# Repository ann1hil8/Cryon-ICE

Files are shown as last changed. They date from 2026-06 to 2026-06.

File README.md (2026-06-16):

# Cryon-ICE: High-Performance RISC-V Target Emulator & Hardware Debugger

Cryon-ICE is a high-speed real-time hardware debugger and target emulation platform built on the Microchip PolarFire SoC FPGA architecture. The system serves as an advanced bidirectional interface bridge designed to intercept, analyze, and process target system execution signals with sub-nanosecond timing precision. 

The architecture bridges a multi-core 64-bit Linux-capable RISC-V subsystem and flexible programmable fabric directly to an external emulation pod interface via high-density card edge connectors.

---

## Technical Architecture Overview

### 1. System Function & Target Application
* **Real-Time Emulation:** Provides deterministic, ultra-low-latency tracking and signal injection for vintage and modern processing buses.
* **Signal Intercept:** Actively hooks into address, data, and control structures of external hardware targets through dedicated, direction-controlled level shifters.
* **Bus Topologies:** Supports a universal expansion bus configuration, currently mapped to a physical PCIe card edge connector profile to interface directly with modular target emulation pods.

### 2. Primary Processing Core
The platform core utilizes the **Microchip PolarFire SoC FPGA** which integrates a hardened coherent CPU cluster alongside non-volatile programmable logic fabric.

* **Exact Part Number:** `MPFS025TC-FCVG484I` (Industrial Temperature Variant, 25K Logic Elements).
* **Microprocessor Sub-System (MSS):** * 1x RV64IMAC Monitor Core (E51 Performance Profile).
  * 4x RV64GC Application Cores (U54 Performance Profile, coherent execution cluster).
  * Hardened memory controllers supporting secure boot, asset protection, and full operating system execution (Linux).
* **Reference Baselines:** Hardware schematics and subsystem initialization fabrics are cross-referenced from the **BeagleV-Fire** open-hardware specification and the **MPFS-ICICLE-KIT** (PolarFire SoC Icicle Development Kit) base architectures.

### 3. Physical Mechanical Package
* **Package Designation:** `FCVG484` (Fine Pitch Flip-Chip Ball Grid Array).
* **Physical Package Envelope:** 19.0 mm x 19.0 mm square molded body package size.
* **Pin Matrix Array:** 484 physical active solder spheres mapped to a 22 x 22 structural matrix grid.
* **Ball Pitch ($P$):** 0.8 mm center-to-center pad spacing. This allows routing single escape tracks using conventional, cost-effective mechanical micro-drills rather than high-density interconnect (HDI) laser-vias.

### 4. PCB Design & Layout Constraints

#### Thermal and Decoupling Void
The physical layout strips away all copper landing pads within the center core of the 22 x 22 BGA matrix configuration, mirroring the physical depopulated ring profile of the `FCVG484` package silicon. This provides two critical routing advantages:
* **Decoupling Optimization:** Low-inductance 0.1 uF ceramic decoupling capacitors are placed directly on the bottom side of the PCB (Layer 4/6), directly beneath the processor power balls to suppress high-frequency transients.
* **Thermal Sink:** The internal center cavity is flooded with a continuous, unbroken Ground copper polygon pour on the outer layer, functioning as an integrated cooling block connected directly to internal system return layers.

#### Physical Layer Stackup Blueprint
The system requires a minimum of a 4-Layer or 6-Layer impedance-controlled configuration:
* **Layer 1 (Top/F.Cu):** Microstrip routing paths, BGA outer escape rings, high-speed transceiver runs, and level-shifter landing pads.
* **Layer 2 (Inner 1/In1.Cu):** Continuous, uninterrupted Ground ($GND$) reference plane. Provides immediate shield parameters for high-density breakout tracks.
* **Layer 3 (Inner 2/In2.Cu):** Split Power Plane ($V_{\text{DD}}$ Core Logic, $V_{\text{DDA}}$ Transceiver Supplies, and 3.3 V / 5.0 V I/O Peripheral Rails).
* **Layer 4 (Bottom/B.Cu):** Passives, decoupling capacitors under the BGA core cavity, and secondary escape routing structures.

---

## CAD Design Rules Matrix (KiCad Netclasses)

The board layout is constrained by specific routing rules configured within the project netclass matrix. Tracks are auto-routed and routed manually using single-ended configurations without generating layout violations.

| Net Class Name | Clearance | Track Width | Via Size | Via Drill | uVia Size | uVia Drill | DP Width | DP Gap |
| :--- | :--- | :--- | :--- | :--- | :--- | :--- | :--- | :--- |
| `BGA_Escape` | 0.127 mm | 0.127 mm | 0.400 mm | 0.200 mm | 0.400 mm | 0.200 mm | 0.127 mm | 0.150 mm |
| `Universal_Bus` | 0.150 mm | 0.200 mm | 0.600 mm | 0.300 mm | 0.600 mm | 0.300 mm | 0.200 mm | 0.200 mm |
| `Power_GND` | 0.200 mm | 0.500 mm | 0.800 mm | 0.400 mm | 0.800 mm | 0.400 mm | 0.600 mm | 0.250 mm |
| `Default` | 0.200 mm | 0.200 mm | 0.600 mm | 0.300 mm | 0.300 mm | 0.100 mm | 0.200 mm | 0.250 mm |

### Routing Mechanics
* **BGA Escape Plan:** Escape tracks (0.127 mm width) break out through the diagonal open channels between the BGA pads (0.400 mm pad diameter). Vias are placed inside the center void of each 4-pad diamond cluster to preserve spatial clearances.
* **Bus Expansion:** Upon exiting the physical boundary of the BGA footprint package, traces transition via the `Universal_Bus` netclass rules to 0.200 mm widths to improve trace reliability, signal propagation characteristics, and manufacturing yields over long runs.

---

## Future Roadmap Configurations

### I/O Channel Expansion
* **Target Scale:** Planned upgrade to scale the universal emulation bus up from 48 lines to **64 universal bidirectional I/O channels**.
* **Impact:** Requires mapping additional General Purpose I/O (GPIO) banks from the PolarFire fabric and scaling up the number of transceiver/buffer ICs.

### Alternate Pod Interconnect Profiles
* **Connector Variant Modularity:** Evaluation of replacing or augmenting the baseline standard PCIe card-edge footprint with multi-lane high-density, high-speed connector options (e.g., Amphenol PCIe M.2 Gen 3/Gen 4 card edge or specialized mezzanine interconnects) to decrease overall pod size profiles while protecting high-speed signal integrity.

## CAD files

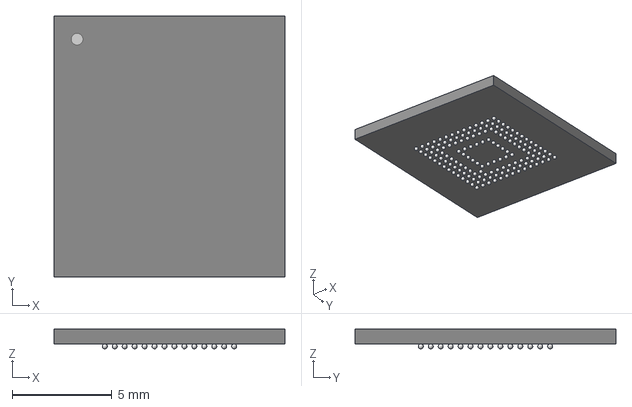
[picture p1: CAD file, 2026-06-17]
Cryon_Library/3D_Models/153BGA_11p5x13x1_MAC.iges
11.6 x 13.1 x 0.993 mm

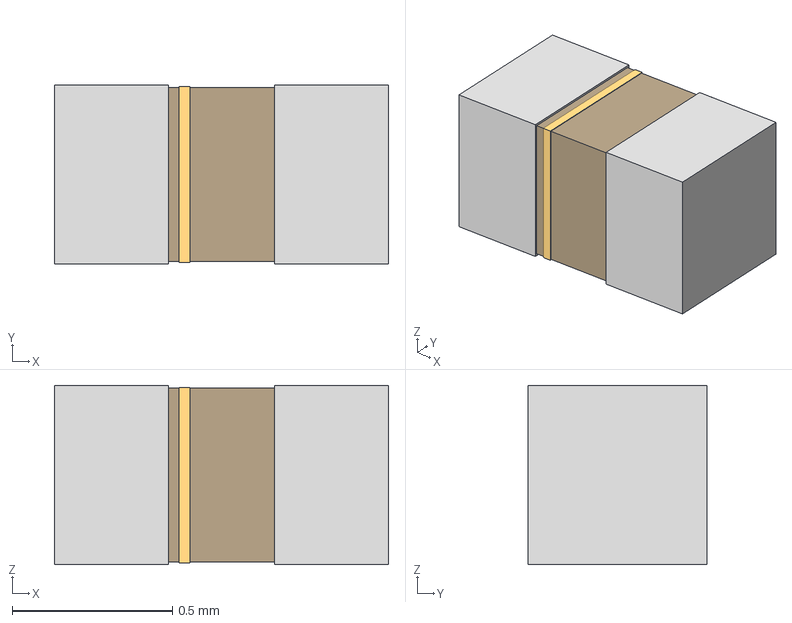
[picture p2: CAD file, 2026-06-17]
Cryon_Library/3D_Models/BLM15P_FBD.iges
1.04 x 0.558 x 0.559 mm

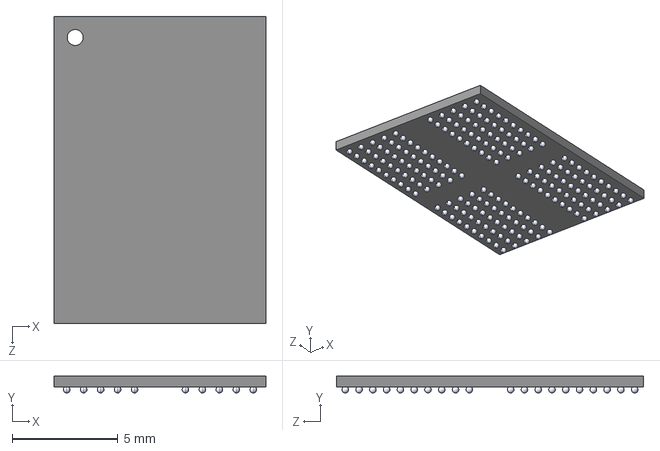
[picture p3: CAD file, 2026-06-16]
Cryon_Library/3D_Models/D1621XM4CDGVI-U.step
10.0 x 0.8 x 14.5 mm

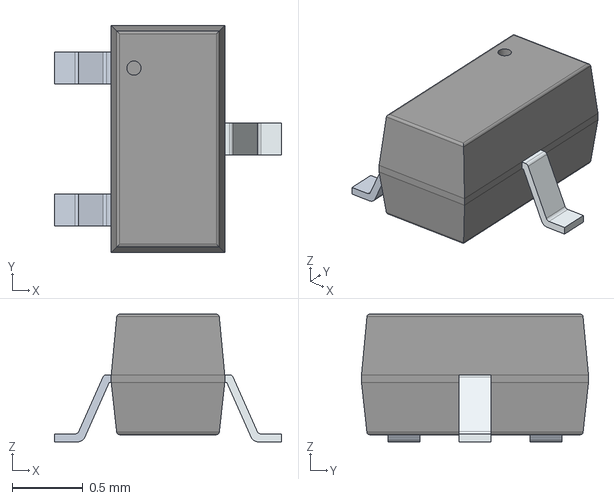
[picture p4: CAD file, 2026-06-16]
Cryon_Library/3D_Models/DMG1012T.iges
1.60 x 1.60 x 0.9 mm

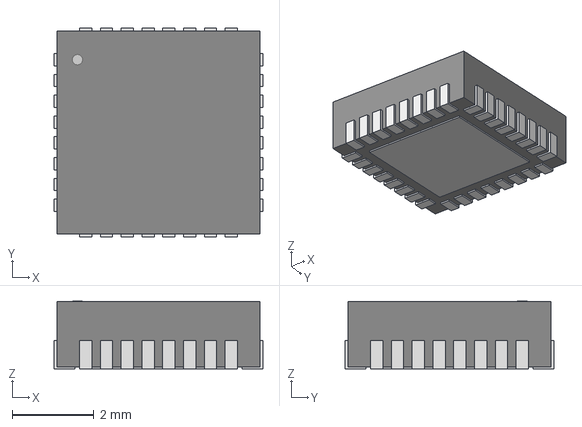
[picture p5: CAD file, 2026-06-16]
Cryon_Library/3D_Models/QFN32_5X5MC_MCH.iges
5.11 x 5.11 x 1.65 mm

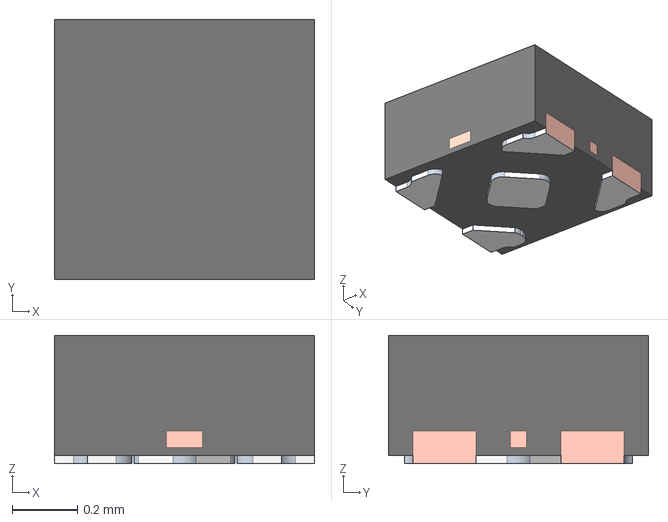
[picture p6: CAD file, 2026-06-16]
Cryon_Library/3D_Models/DPW0005A.iges
0.8 x 0.8 x 0.395 mm

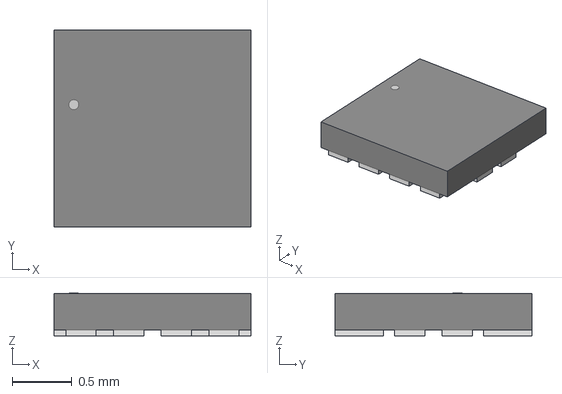
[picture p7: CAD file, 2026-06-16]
Cryon_Library/3D_Models/SOT1355-1_X2QFN12_NXP.iges
1.65 x 1.65 x 0.358 mm

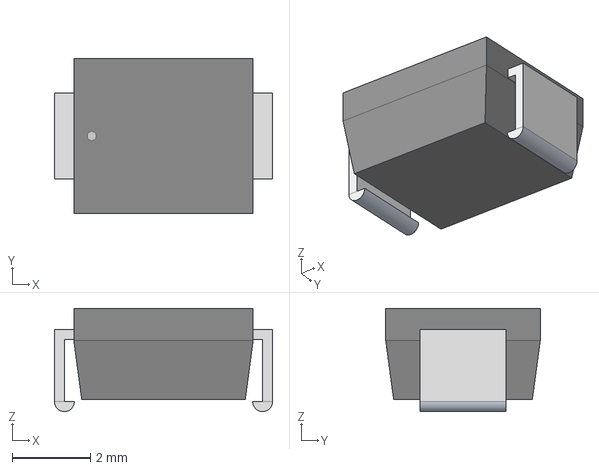
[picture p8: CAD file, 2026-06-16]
Cryon_Library/3D_Models/SMB_STM.iges
5.59 x 3.96 x 2.64 mm

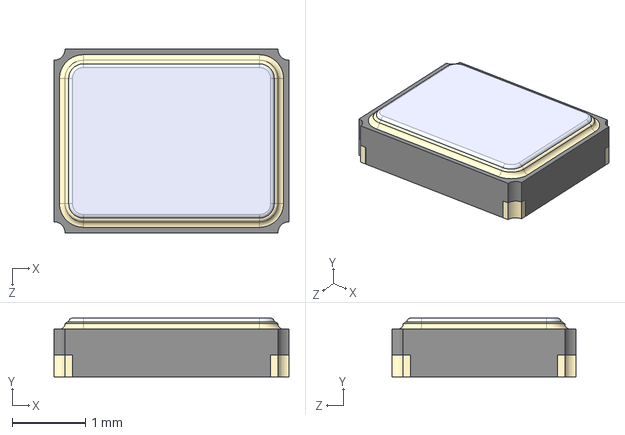
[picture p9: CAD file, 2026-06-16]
Cryon_Library/3D_Models/12-88481.step
3.20 x 0.8 x 2.50 mm

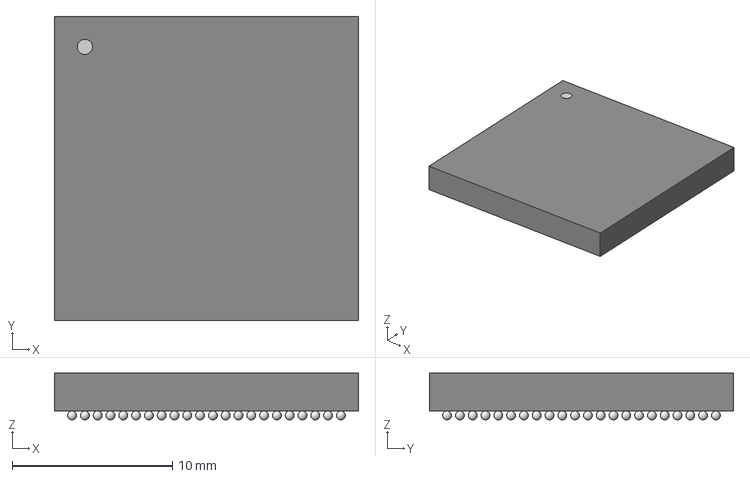
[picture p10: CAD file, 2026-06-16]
Cryon_Library/3D_Models/MPFS250TMPFS160TMPFS095TMPFS025T-FCVG484_MCH.step
19.0 x 19.0 x 2.92 mm

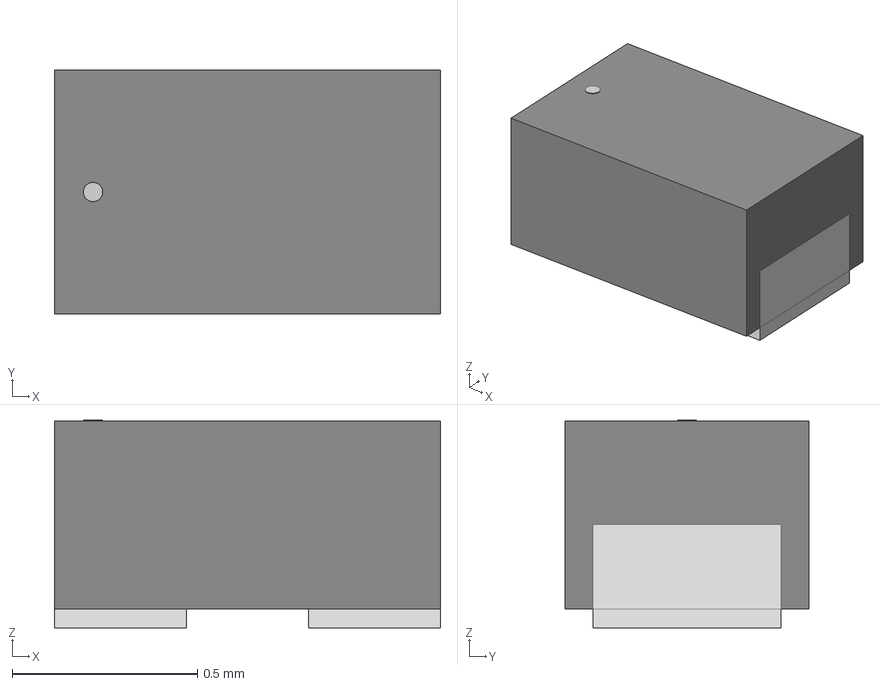
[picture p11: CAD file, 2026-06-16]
Cryon_Library/3D_Models/CR_DFN1006-2_GAS.iges
1.04 x 0.66 x 0.561 mm

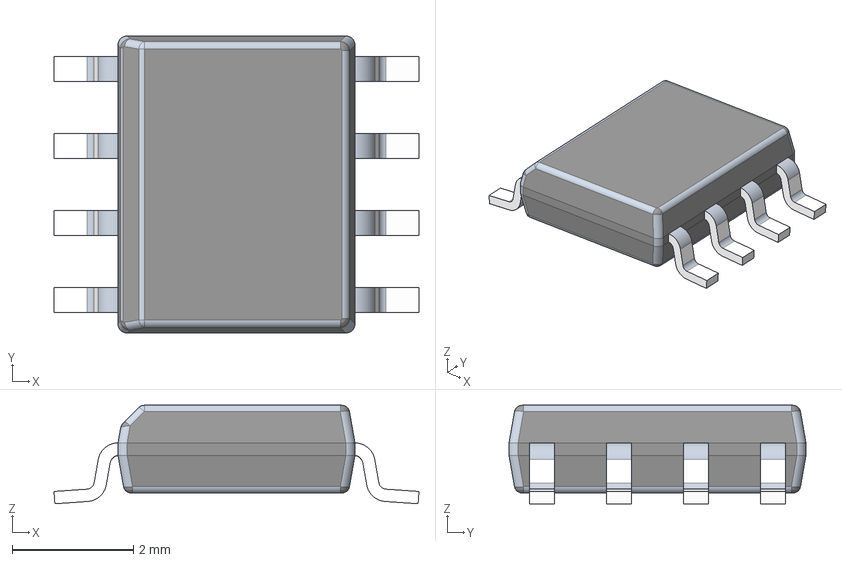
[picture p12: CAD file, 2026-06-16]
Cryon_Library/3D_Models/D0008A.iges
6.02 x 4.90 x 1.63 mm

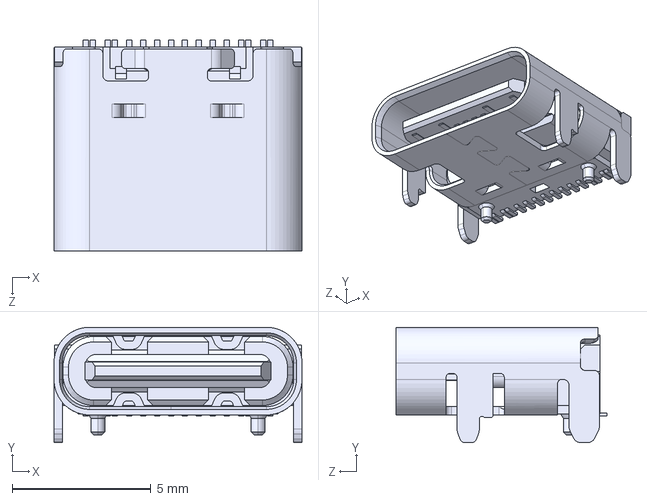
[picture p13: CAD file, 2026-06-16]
Cryon_Library/3D_Models/10155435-00011LF.STEP
8.94 x 4.16 x 7.60 mm

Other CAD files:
Cryon_Library/3D_Models/10155435-00011LF.stp
Cryon_Library/3D_Models/MPFS250TMPFS160TMPFS095TMPFS025T-FCVG484_MCH.iges

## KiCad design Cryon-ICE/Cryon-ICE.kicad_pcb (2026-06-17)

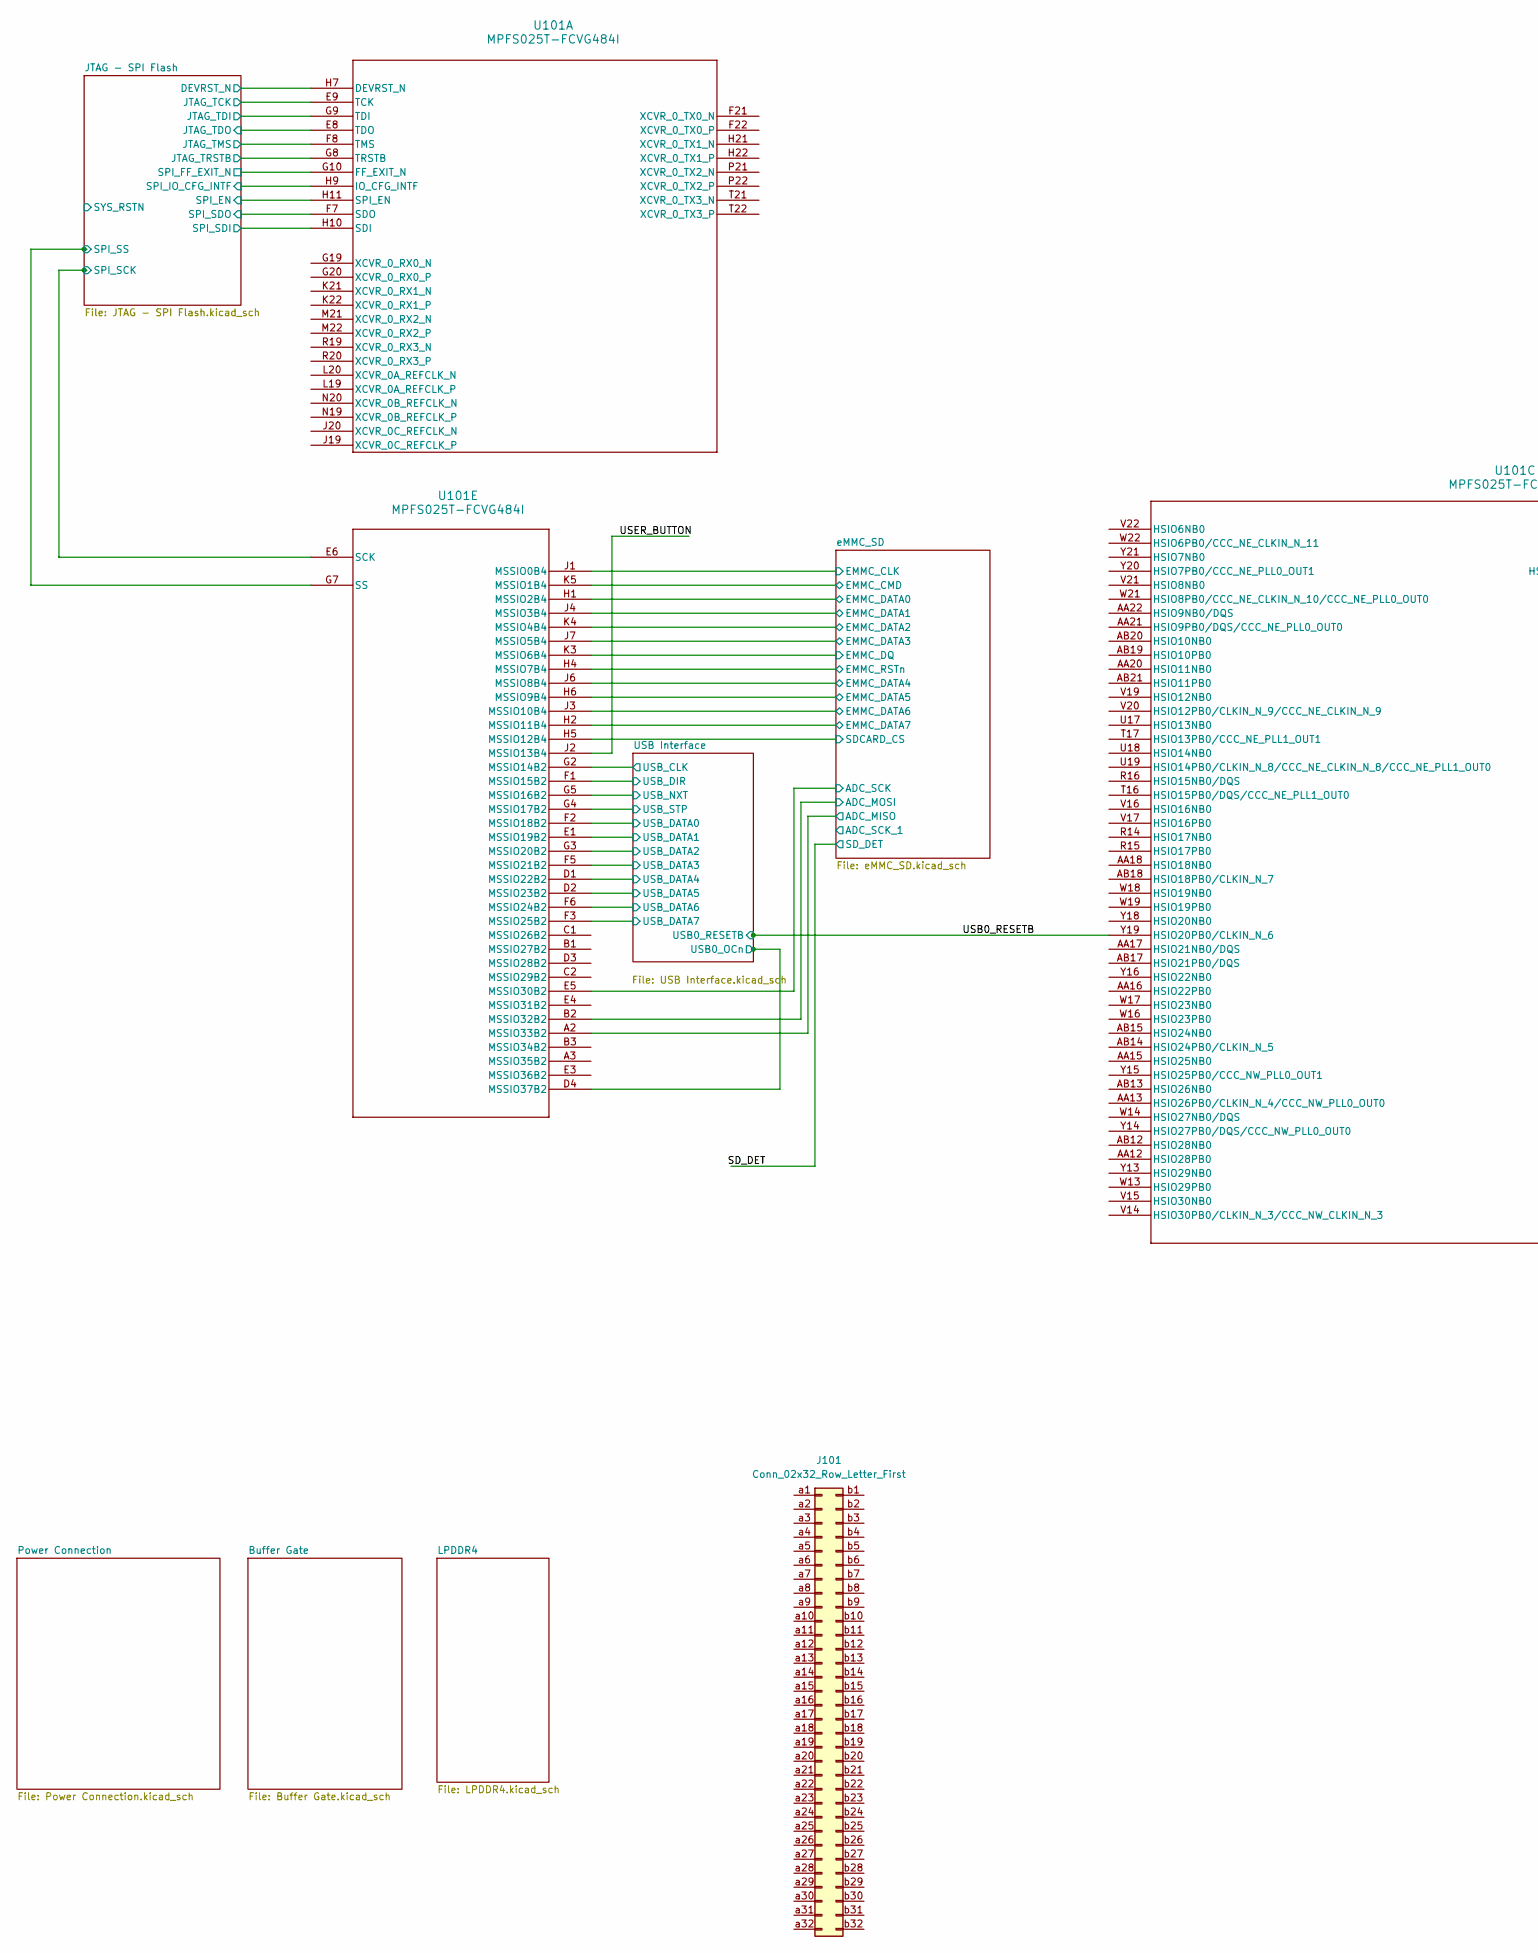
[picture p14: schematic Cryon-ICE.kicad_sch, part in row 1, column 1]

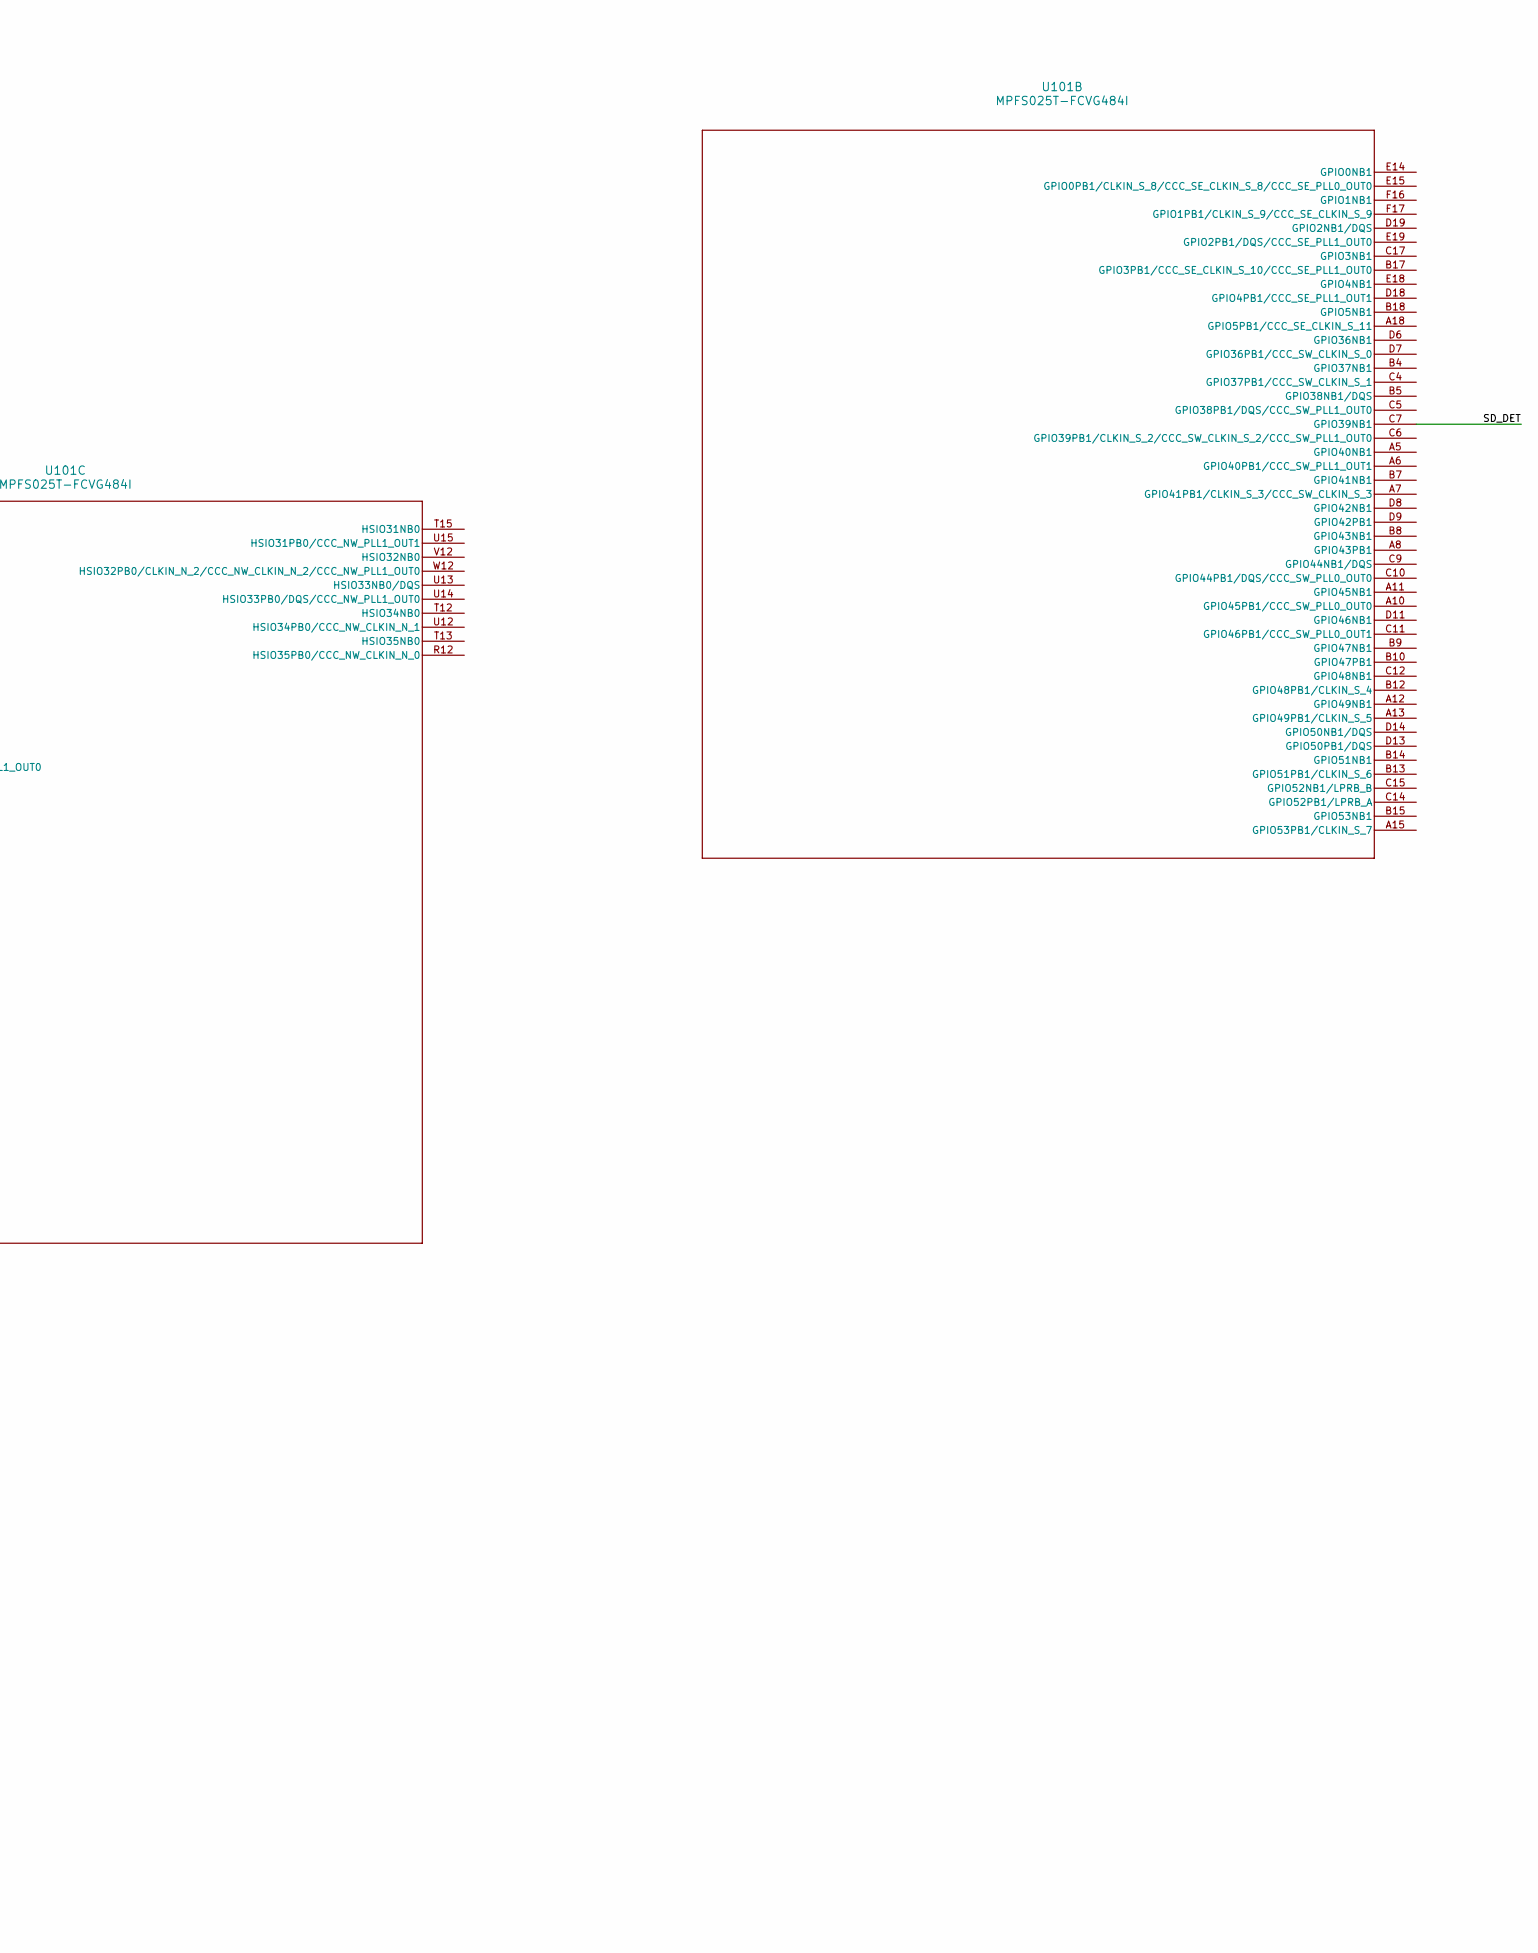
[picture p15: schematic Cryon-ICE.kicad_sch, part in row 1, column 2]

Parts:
J101: Conn_02x32_Row_Letter_First; BUS_PCIexpress_x4
U101: MPFS025T-FCVG484I; MPFS250T&slash_MPFS160T&slash_MPFS095T&slash_MPFS025T-FCVG4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

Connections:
/JTAG - SPI Flash/DEVRST_N: U101.H7 (DEVRST_N); also elsewhere on the board
/JTAG - SPI Flash/JTAG_TDO: U101.E8 (TDO); also elsewhere on the board
/JTAG - SPI Flash/JTAT_TCK: U101.E9 (TCK); also elsewhere on the board
/JTAG - SPI Flash/JTAT_TDI: U101.G9 (TDI); also elsewhere on the board
/JTAG - SPI Flash/JTAT_TMS: U101.F8 (TMS); also elsewhere on the board
/JTAG - SPI Flash/JTAT_TRSTB: U101.G8 (TRSTB); also elsewhere on the board
/JTAG - SPI Flash/SPI_EN: U101.H11 (SPI_EN); also elsewhere on the board
/JTAG - SPI Flash/SPI_FF_EXIT_N: U101.G10 (FF_EXIT_N); also elsewhere on the board
/JTAG - SPI Flash/SPI_MISO: U101.H10 (SDI); also elsewhere on the board
/JTAG - SPI Flash/SPI_MODE: U101.H9 (IO_CFG_INTF); also elsewhere on the board
/JTAG - SPI Flash/SPI_SCK: U101.E6 (SCK); also elsewhere on the board
/JTAG - SPI Flash/SPI_SDO: U101.F7 (SDO); also elsewhere on the board
/JTAG - SPI Flash/SPI_SS: U101.G7 (SS); also elsewhere on the board
/SD_DET: U101.C7 (GPIO39NB1); also elsewhere on the board
/USB0_RESETB: U101.Y19 (HSIO20PB0/CLKIN_N_6); also elsewhere on the board
/USB Interface/USB0_OCn: U101.D4 (MSSIO37B2); also elsewhere on the board
/USB Interface/USB_CLK: U101.G2 (MSSIO14B2); also elsewhere on the board
/USB Interface/USB_DATA0: U101.F2 (MSSIO18B2); also elsewhere on the board
/USB Interface/USB_DATA1: U101.E1 (MSSIO19B2); also elsewhere on the board
/USB Interface/USB_DATA2: U101.G3 (MSSIO20B2); also elsewhere on the board
/USB Interface/USB_DATA3: U101.F5 (MSSIO21B2); also elsewhere on the board
/USB Interface/USB_DATA4: U101.D1 (MSSIO22B2); also elsewhere on the board
/USB Interface/USB_DATA5: U101.D2 (MSSIO23B2); also elsewhere on the board
/USB Interface/USB_DATA6: U101.F6 (MSSIO24B2); also elsewhere on the board
/USB Interface/USB_DATA7: U101.F3 (MSSIO25B2); also elsewhere on the board
/USB Interface/USB_DIR: U101.F1 (MSSIO15B2); also elsewhere on the board
/USB Interface/USB_NXT: U101.G5 (MSSIO16B2); also elsewhere on the board
/USB Interface/USB_STP: U101.G4 (MSSIO17B2); also elsewhere on the board
/USER_BUTTON: U101.J2 (MSSIO13B4)
/eMMC_SD/ADC_MISO: U101.A2 (MSSIO33B2); also elsewhere on the board
/eMMC_SD/ADC_MOSI: U101.B2 (MSSIO32B2); also elsewhere on the board
/eMMC_SD/ADC_SCK: U101.E5 (MSSIO30B2); also elsewhere on the board
/eMMC_SD/EMMC_CLK: U101.J1 (MSSIO0B4); also elsewhere on the board
/eMMC_SD/EMMC_CMD: U101.K5 (MSSIO1B4); also elsewhere on the board
/eMMC_SD/EMMC_DATA0: U101.H1 (MSSIO2B4); also elsewhere on the board
/eMMC_SD/EMMC_DATA1: U101.J4 (MSSIO3B4); also elsewhere on the board
/eMMC_SD/EMMC_DATA2: U101.K4 (MSSIO4B4); also elsewhere on the board
/eMMC_SD/EMMC_DATA3: U101.J7 (MSSIO5B4); also elsewhere on the board
/eMMC_SD/EMMC_DATA4: U101.J6 (MSSIO8B4); also elsewhere on the board
/eMMC_SD/EMMC_DATA5: U101.H6 (MSSIO9B4); also elsewhere on the board
/eMMC_SD/EMMC_DATA6: U101.J3 (MSSIO10B4); also elsewhere on the board
/eMMC_SD/EMMC_DATA7: U101.H2 (MSSIO11B4); also elsewhere on the board
/eMMC_SD/EMMC_DQ: U101.K3 (MSSIO6B4); also elsewhere on the board
/eMMC_SD/EMMC_RSTn: U101.H4 (MSSIO7B4); also elsewhere on the board
/eMMC_SD/SDCARD_CS: U101.H5 (MSSIO12B4); also elsewhere on the board

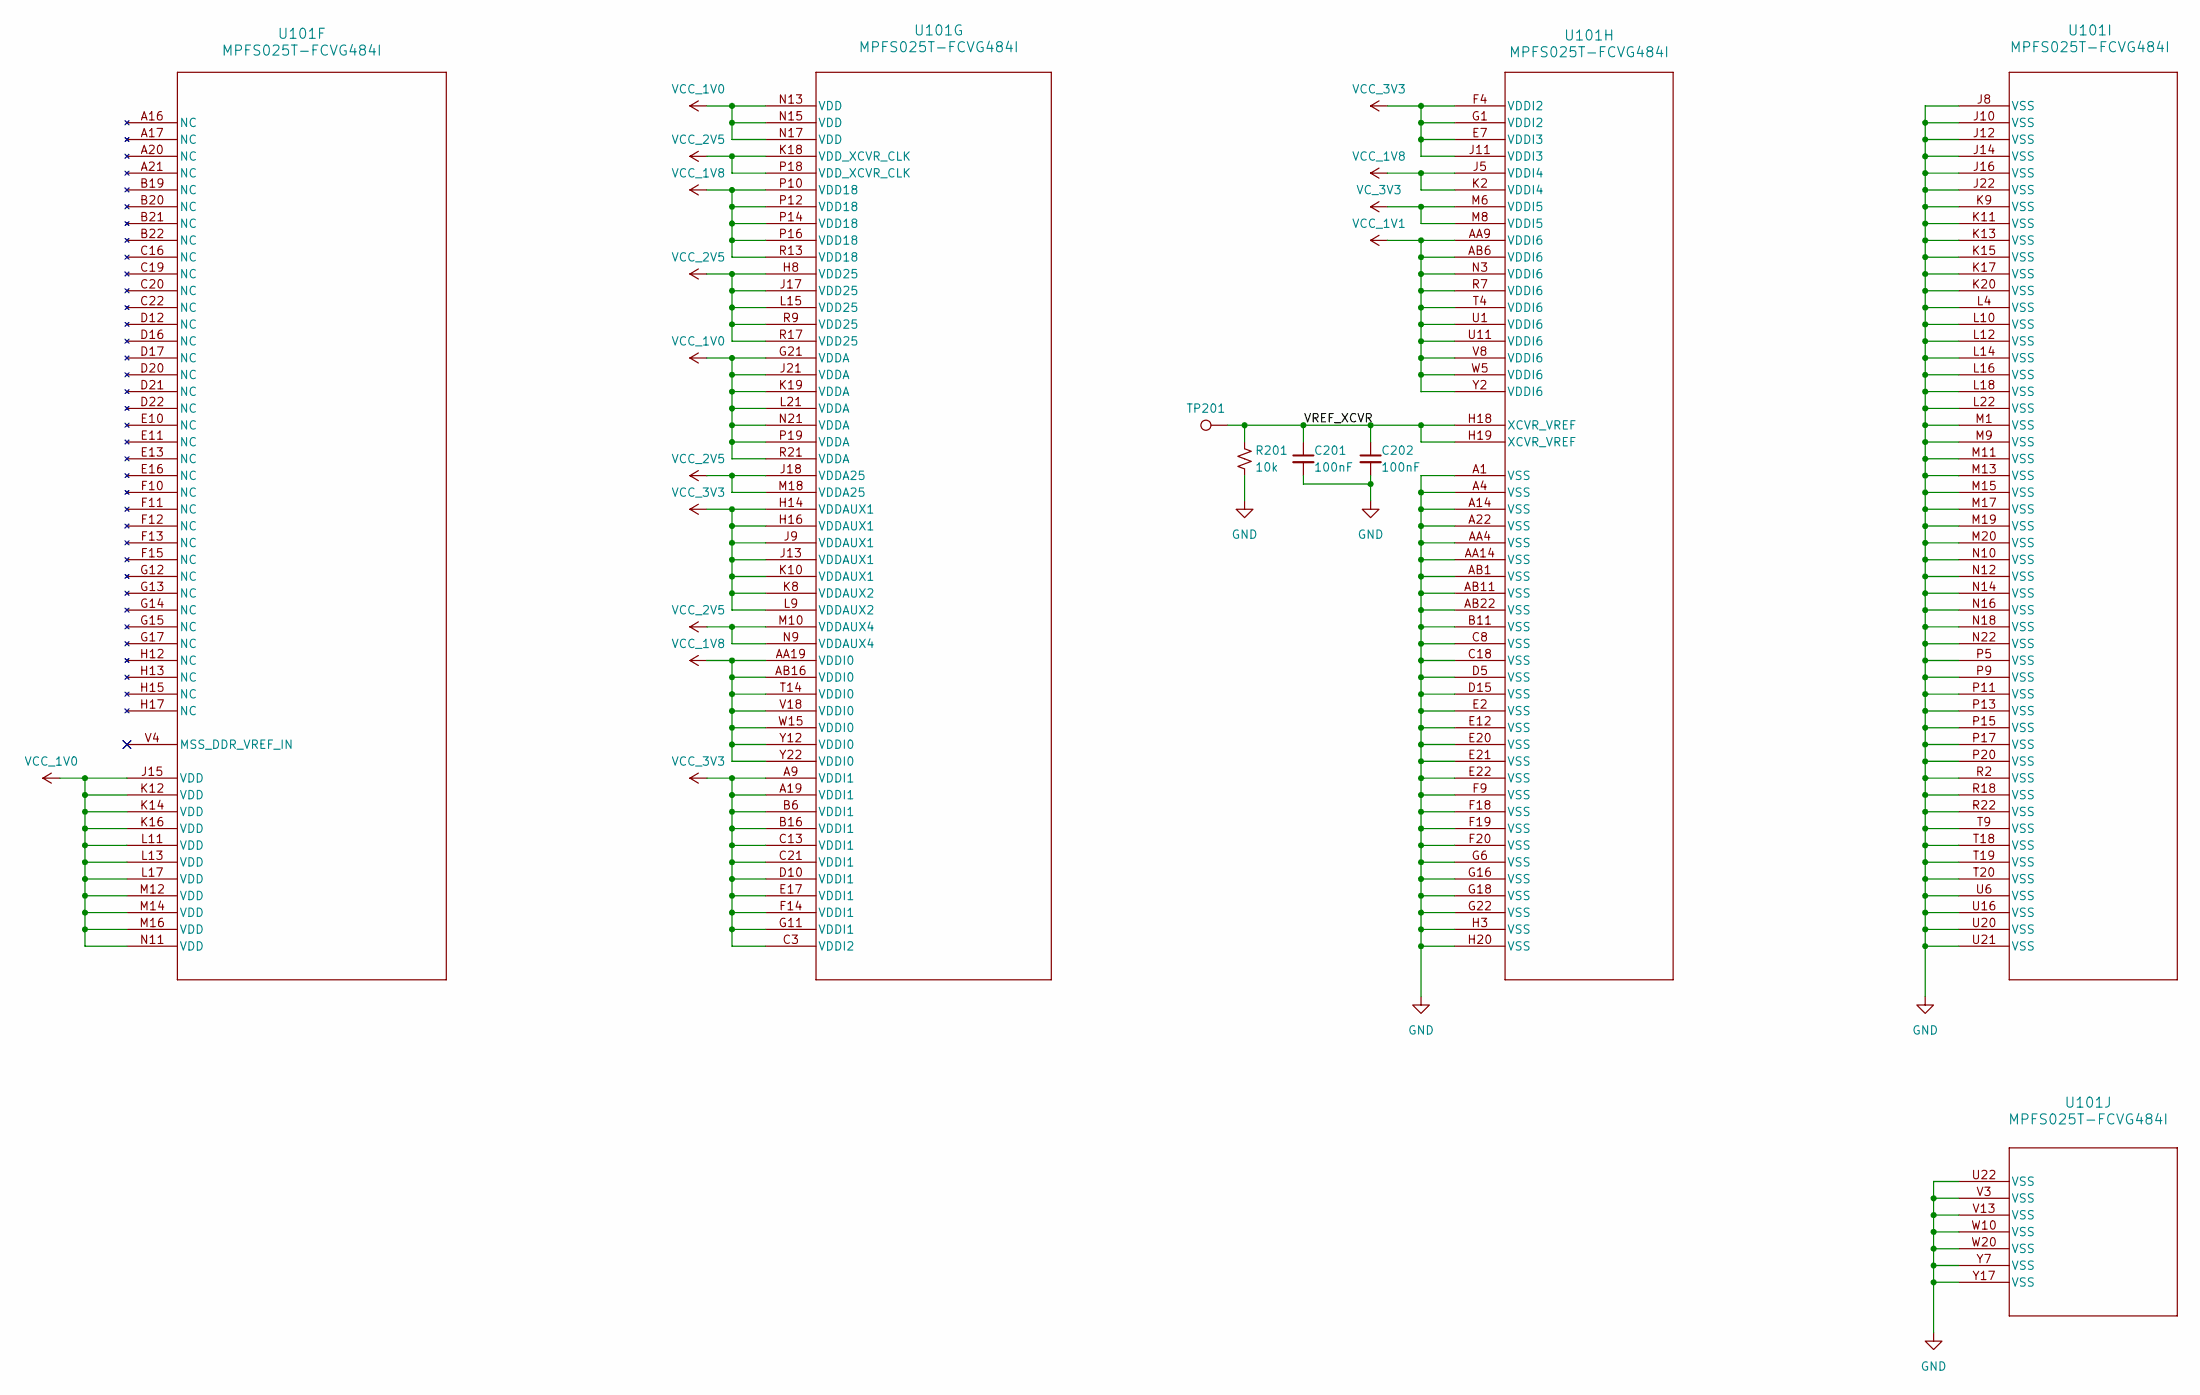
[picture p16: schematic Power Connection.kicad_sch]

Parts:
C201, C202: 100nF; C_0201_0603Metric
R201: 10k; R_0402_1005Metric
TP201: TestPoint; TestPoint_Pad_D1.0mm
U101: MPFS025T-FCVG484I; MPFS250T&slash_MPFS160T&slash_MPFS095T&slash_MPFS025T-FCVG4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

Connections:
/Power Connection/VREF_XCVR: C201.1, C202.1, R201.1, TP201.1 (1_1), U101.H18 (XCVR_VREF), U101.H19 (XCVR_VREF)
GND: C201.2, C202.2, R201.2, U101.A1 (VSS), U101.A4 (VSS), U101.A14 (VSS), U101.A22 (VSS), U101.AA4 (VSS), U101.AA14 (VSS), U101.AB1 (VSS), U101.AB11 (VSS), U101.AB22 (VSS), U101.B11 (VSS), U101.C8 (VSS), U101.C18 (VSS), U101.D5 (VSS), U101.D15 (VSS), U101.E2 (VSS), U101.E12 (VSS), U101.E20 (VSS), U101.E21 (VSS), U101.E22 (VSS), U101.F9 (VSS), U101.F18 (VSS), U101.F19 (VSS), U101.F20 (VSS), U101.G6 (VSS), U101.G16 (VSS), U101.G18 (VSS), U101.G22 (VSS), U101.H3 (VSS), U101.H20 (VSS), U101.J8 (VSS), U101.J10 (VSS), U101.J12 (VSS), U101.J14 (VSS), U101.J16 (VSS), U101.J22 (VSS), U101.K9 (VSS), U101.K11 (VSS), U101.K13 (VSS), U101.K15 (VSS), U101.K17 (VSS), U101.K20 (VSS), U101.L4 (VSS), U101.L10 (VSS), U101.L12 (VSS), U101.L14 (VSS), U101.L16 (VSS), U101.L18 (VSS), U101.L22 (VSS), U101.M1 (VSS), U101.M9 (VSS), U101.M11 (VSS), U101.M13 (VSS), U101.M15 (VSS), U101.M17 (VSS), U101.M19 (VSS), U101.M20 (VSS), U101.N10 (VSS), U101.N12 (VSS), U101.N14 (VSS), U101.N16 (VSS), U101.N18 (VSS), U101.N22 (VSS), U101.P5 (VSS), U101.P9 (VSS), U101.P11 (VSS), U101.P13 (VSS), U101.P15 (VSS), U101.P17 (VSS), U101.P20 (VSS), U101.R2 (VSS), U101.R18 (VSS), U101.R22 (VSS), U101.T9 (VSS), U101.T18 (VSS), U101.T19 (VSS), U101.T20 (VSS), U101.U6 (VSS), U101.U16 (VSS), U101.U20 (VSS), U101.U21 (VSS), U101.U22 (VSS), U101.V3 (VSS), U101.V13 (VSS), U101.W10 (VSS), U101.W20 (VSS), U101.Y7 (VSS), U101.Y17 (VSS); also elsewhere on the board
VCC_1V0: U101.G21 (VDDA), U101.J15 (VDD), U101.J21 (VDDA), U101.K12 (VDD), U101.K14 (VDD), U101.K16 (VDD), U101.K19 (VDDA), U101.L11 (VDD), U101.L13 (VDD), U101.L17 (VDD), U101.L21 (VDDA), U101.M12 (VDD), U101.M14 (VDD), U101.M16 (VDD), U101.N11 (VDD), U101.N13 (VDD), U101.N15 (VDD), U101.N17 (VDD), U101.N21 (VDDA), U101.P19 (VDDA), U101.R21 (VDDA)
VCC_1V1: U101.AA9 (VDDI6), U101.AB6 (VDDI6), U101.N3 (VDDI6), U101.R7 (VDDI6), U101.T4 (VDDI6), U101.U1 (VDDI6), U101.U11 (VDDI6), U101.V8 (VDDI6), U101.W5 (VDDI6), U101.Y2 (VDDI6); also elsewhere on the board
VCC_1V8: U101.AA19 (VDDI0), U101.AB16 (VDDI0), U101.J5 (VDDI4), U101.K2 (VDDI4), U101.P10 (VDD18), U101.P12 (VDD18), U101.P14 (VDD18), U101.P16 (VDD18), U101.R13 (VDD18), U101.T14 (VDDI0), U101.V18 (VDDI0), U101.W15 (VDDI0), U101.Y12 (VDDI0), U101.Y22 (VDDI0); also elsewhere on the board
VCC_2V5: U101.H8 (VDD25), U101.J17 (VDD25), U101.J18 (VDDA25), U101.K18 (VDD_XCVR_CLK), U101.L15 (VDD25), U101.M10 (VDDAUX4), U101.M18 (VDDA25), U101.N9 (VDDAUX4), U101.P18 (VDD_XCVR_CLK), U101.R9 (VDD25), U101.R17 (VDD25)
VCC_3V3: U101.A9 (VDDI1), U101.A19 (VDDI1), U101.B6 (VDDI1), U101.B16 (VDDI1), U101.C3 (VDDI2), U101.C13 (VDDI1), U101.C21 (VDDI1), U101.D10 (VDDI1), U101.E7 (VDDI3), U101.E17 (VDDI1), U101.F4 (VDDI2), U101.F14 (VDDI1), U101.G1 (VDDI2), U101.G11 (VDDI1), U101.H14 (VDDAUX1), U101.H16 (VDDAUX1), U101.J9 (VDDAUX1), U101.J11 (VDDI3), U101.J13 (VDDAUX1), U101.K8 (VDDAUX2), U101.K10 (VDDAUX1), U101.L9 (VDDAUX2); also elsewhere on the board
VC_3V3: U101.M6 (VDDI5), U101.M8 (VDDI5)

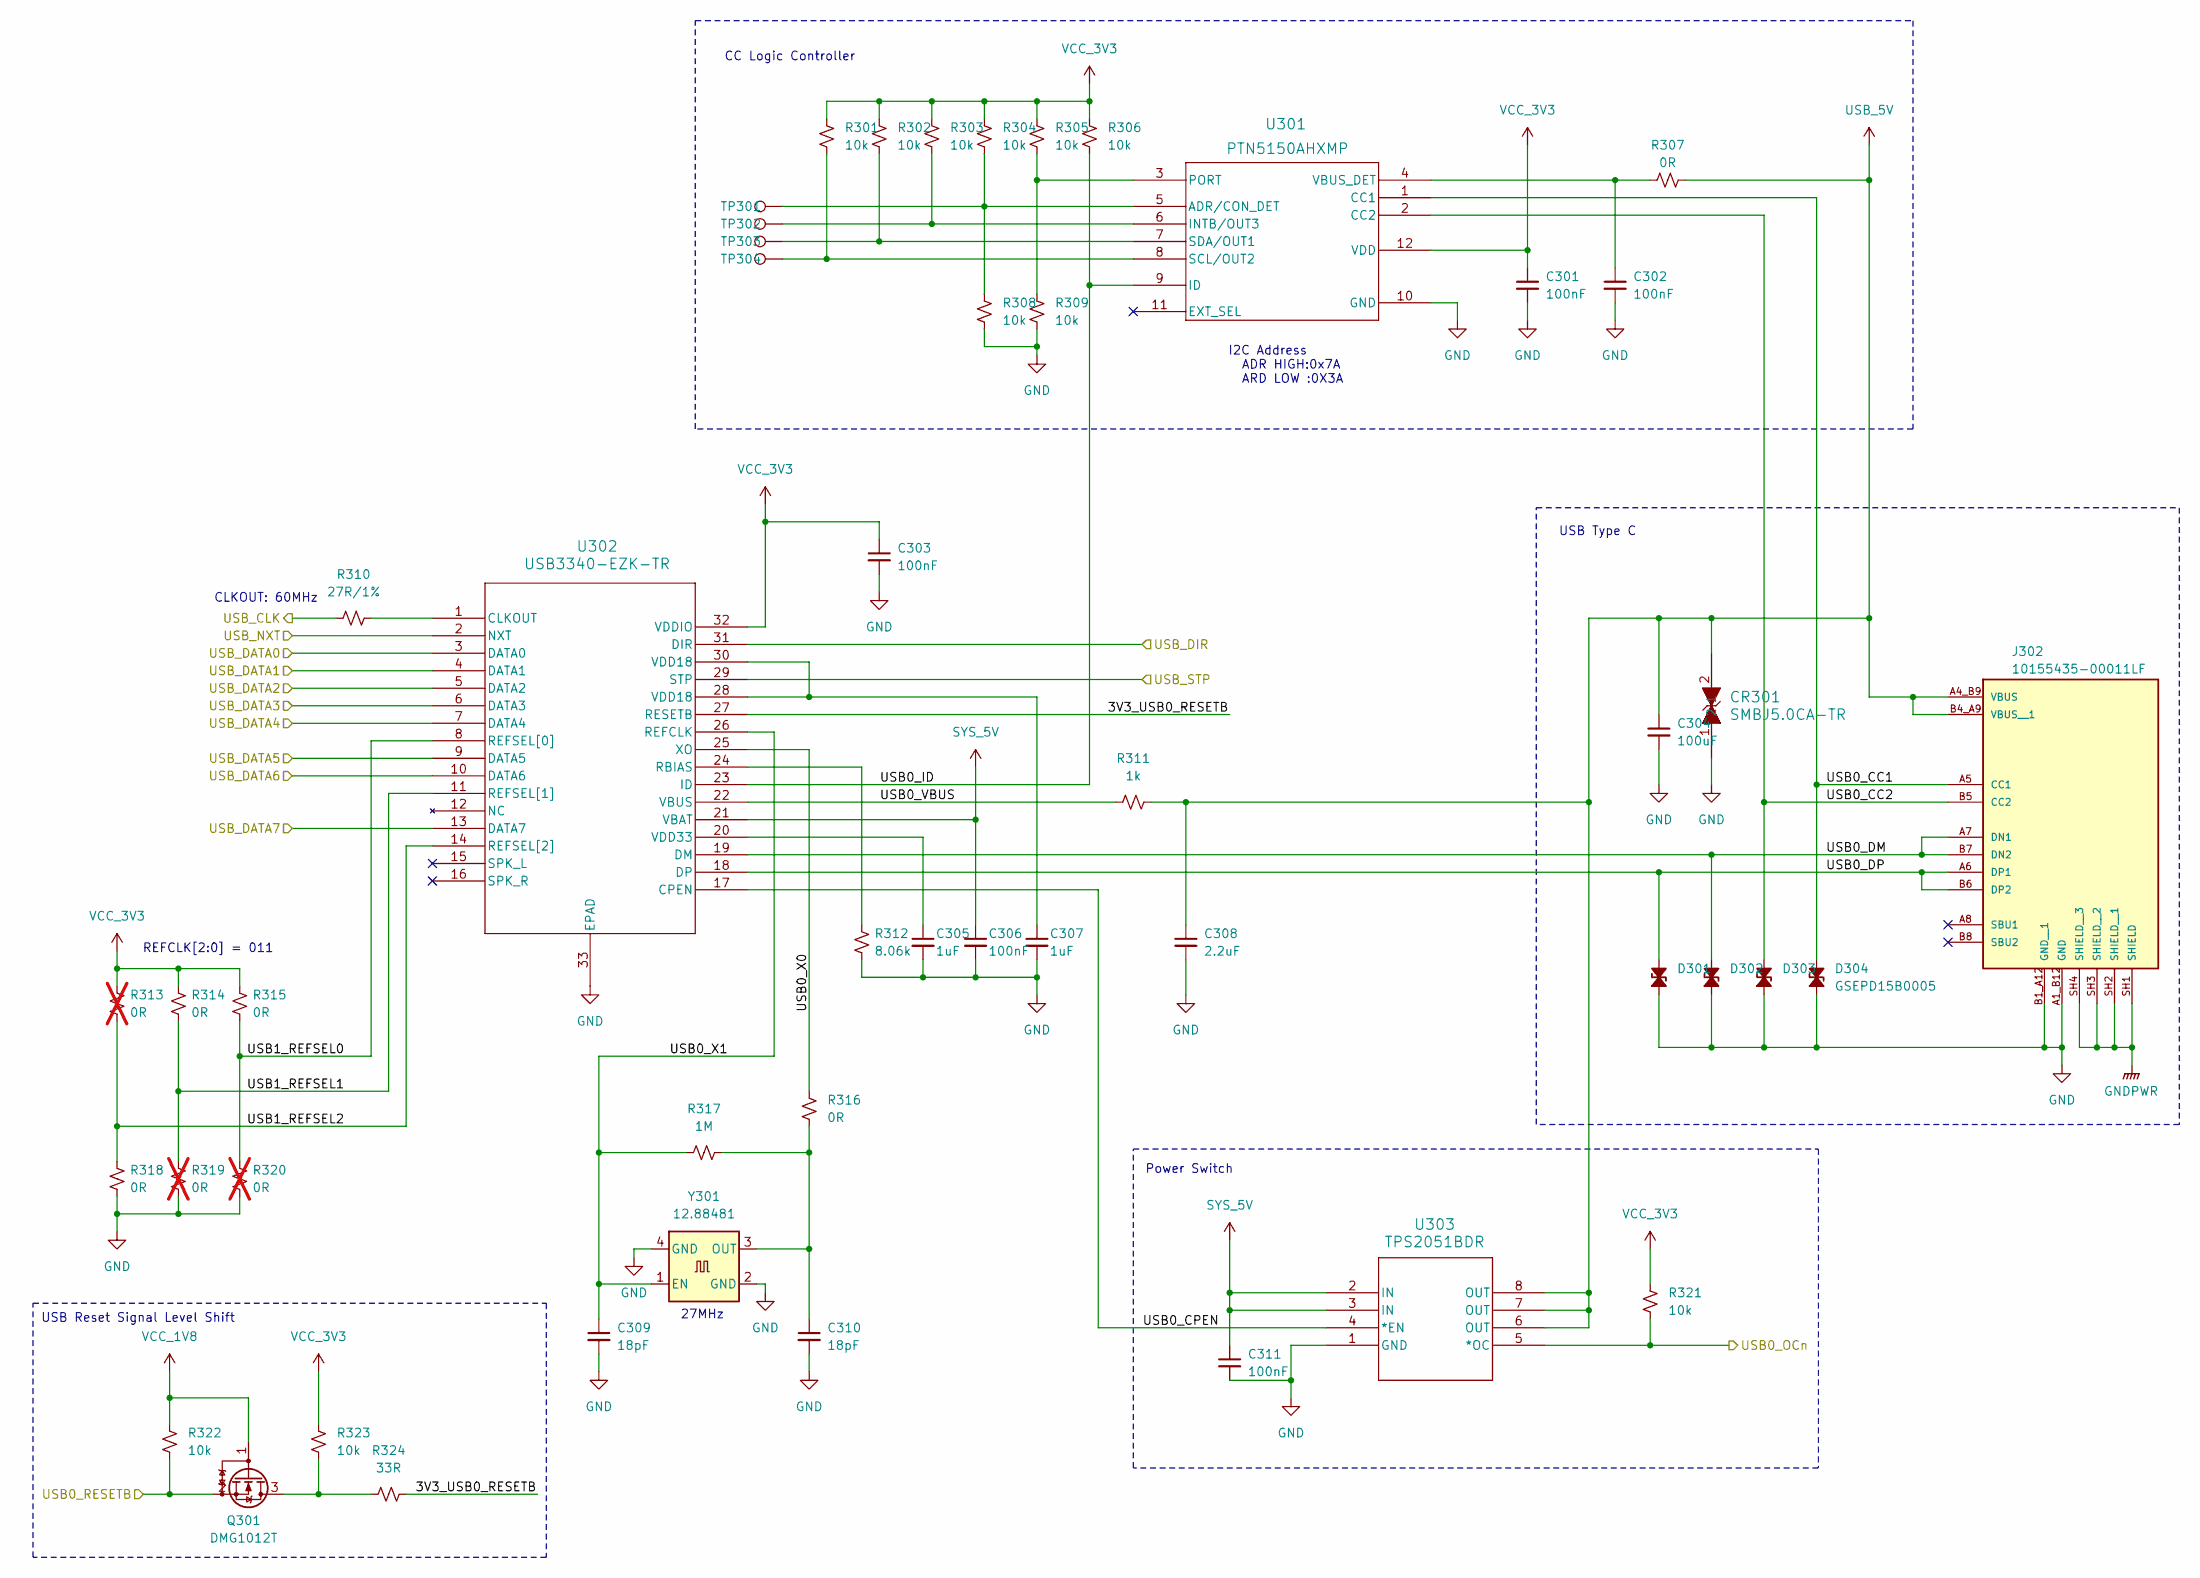
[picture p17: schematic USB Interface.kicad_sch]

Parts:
C301, C302, C303, C306, C311: 100nF; C_0402_1005Metric
C304: 100uF; C_0402_1005Metric
C305, C307: 1uF; C_0402_1005Metric
C308: 2.2uF; C_0603_1608Metric
C309, C310: 18pF; C_0402_1005Metric
CR301: SMBJ5.0CA-TR; SMB_STM
D301, D302, D303, D304: GSEPD15B0005; D_GSEPD15B0005_01005_0402Metric
J302: 10155435-00011LF; AMPHENOL_10155435-00011LF; PARTREV C
Q301: DMG1012T; DMG1012-SOT-523
R301, R302, R303, R304, R305, R306, R308, R309, R321, R322, R323: 10k; R_0402_1005Metric
R307, R314, R315, R316, R318: 0R; R_0402_1005Metric
R310: 27R/1%; R_0402_1005Metric
R311: 1k; R_0402_1005Metric
R312: 8.06k; R_0402_1005Metric
R313, R319, R320: 0R; R_0402_1005Metric; not fitted
R317: 1M; R_0402_1005Metric
R324: 33R; R_0402_1005Metric
TP301, TP302, TP303, TP304: TestPoint; TestPoint_Pad_D1.0mm
U301: PTN5150AHXMP; SOT1355-1_X2QFN12_NXP
U302: USB3340-EZK-TR; QFN32_5X5MC_MCH
U303: TPS2051BDR; D8
Y301: 12.88481; Oscillator_SMD_12.88481_EuroQuartz_XO32-4Pin_3.2x2.5mm

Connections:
/USB0_RESETB: Q301.2 (S), R322.2; also elsewhere on the board
/USB Interface/3V3_USB0_RESETB: R324.2, U302.27 (RESETB)
/USB Interface/USB0_CC1: D304.2 (A2), J302.A5 (CC1), U301.1 (CC1)
/USB Interface/USB0_CC2: D303.2 (A2), J302.B5 (CC2), U301.2 (CC2)
/USB Interface/USB0_CPEN: U302.17 (CPEN), U303.4 (*EN)
/USB Interface/USB0_DM: D302.2 (A2), J302.A7 (DN1), J302.B7 (DN2), U302.19 (DM)
/USB Interface/USB0_DP: D301.2 (A2), J302.A6 (DP1), J302.B6 (DP2), U302.18 (DP)
/USB Interface/USB0_ID: R306.2, U301.9 (ID), U302.23 (ID)
/USB Interface/USB0_OCn: R321.2, U303.5 (*OC); also elsewhere on the board
/USB Interface/USB0_VBUS: R311.1, U302.22 (VBUS)
/USB Interface/USB0_X0: R316.1, U302.25 (XO)
/USB Interface/USB0_X1: C309.1, R317.1, U302.26 (REFCLK), Y301.1 (EN)
/USB Interface/USB1_REFSEL0: R315.2, R320.1, U302.8 (REFSEL[0])
/USB Interface/USB1_REFSEL1: R314.2, R319.1, U302.11 (REFSEL[1])
/USB Interface/USB1_REFSEL2: R313.2, R318.1, U302.14 (REFSEL[2])
/USB Interface/USB_CLK: R310.1; also elsewhere on the board
/USB Interface/USB_DATA0: U302.3 (DATA0); also elsewhere on the board
/USB Interface/USB_DATA1: U302.4 (DATA1); also elsewhere on the board
/USB Interface/USB_DATA2: U302.5 (DATA2); also elsewhere on the board
/USB Interface/USB_DATA3: U302.6 (DATA3); also elsewhere on the board
/USB Interface/USB_DATA4: U302.7 (DATA4); also elsewhere on the board
/USB Interface/USB_DATA5: U302.9 (DATA5); also elsewhere on the board
/USB Interface/USB_DATA6: U302.10 (DATA6); also elsewhere on the board
/USB Interface/USB_DATA7: U302.13 (DATA7); also elsewhere on the board
/USB Interface/USB_DIR: U302.31 (DIR); also elsewhere on the board
/USB Interface/USB_NXT: U302.2 (NXT); also elsewhere on the board
/USB Interface/USB_STP: U302.29 (STP); also elsewhere on the board
GND: C301.2, C302.2, C303.2, C304.2, C305.2, C306.2, C307.2, C308.2, C309.2, C310.2, C311.2, CR301.1, D301.1 (A1), D302.1 (A1), D303.1 (A1), D304.1 (A1), J302.A1_B12 (GND), J302.B1_A12 (GND__1), R308.2, R309.2, R312.2, R318.2, R319.2, R320.2, U301.10 (GND), U302.33 (EPAD), U303.1 (GND), Y301.2 (GND), Y301.4 (GND); also elsewhere on the board
GNDPWR: J302.SH1 (SHIELD), J302.SH2 (SHIELD__1), J302.SH3 (SHIELD__2), J302.SH4 (SHIELD__3)
unnamed: C307.1, U302.28 (VDD18), U302.30 (VDD18)
unnamed: Q301.3 (D), R323.2, R324.1
unnamed: R304.2, R308.1, TP301.1 (1_1), U301.5 (ADR/CON_DET)
unnamed: R303.2, TP302.1 (1_1), U301.6 (INTB/OUT3)
unnamed: R305.2, R309.1, U301.3 (PORT)
unnamed: R301.2, TP304.1 (1_1), U301.8 (SCL/OUT2)
unnamed: R302.2, TP303.1 (1_1), U301.7 (SDA/OUT1)
unnamed: C302.1, R307.1, U301.4 (VBUS_DET)
unnamed: R310.2, U302.1 (CLKOUT)
unnamed: R312.1, U302.24 (RBIAS)
unnamed: C305.1, U302.20 (VDD33)
unnamed: C310.1, R316.2, R317.2, Y301.3 (OUT)
SYS_5V: C306.1, C311.1, U302.21 (VBAT), U303.2 (IN), U303.3 (IN)
USB_5V: C304.1, C308.1, CR301.2, J302.A4_B9 (VBUS), J302.B4_A9 (VBUS__1), R307.2, R311.2, U303.6 (OUT), U303.7 (OUT), U303.8 (OUT)
VCC_1V8: Q301.1 (G), R322.1; also elsewhere on the board
VCC_3V3: C301.1, C303.1, R301.1, R302.1, R303.1, R304.1, R305.1, R306.1, R313.1, R314.1, R315.1, R321.1, R323.1, U301.12 (VDD), U302.32 (VDDIO); also elsewhere on the board

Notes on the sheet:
USB Reset Signal Level Shift
CC Logic Controller
REFCLK[2:0] = 011
27MHz
USB Type C
CLKOUT: 60MHz
I2C Address ADR HIGH:0x7A ARD LOW :0X3A
Power Switch

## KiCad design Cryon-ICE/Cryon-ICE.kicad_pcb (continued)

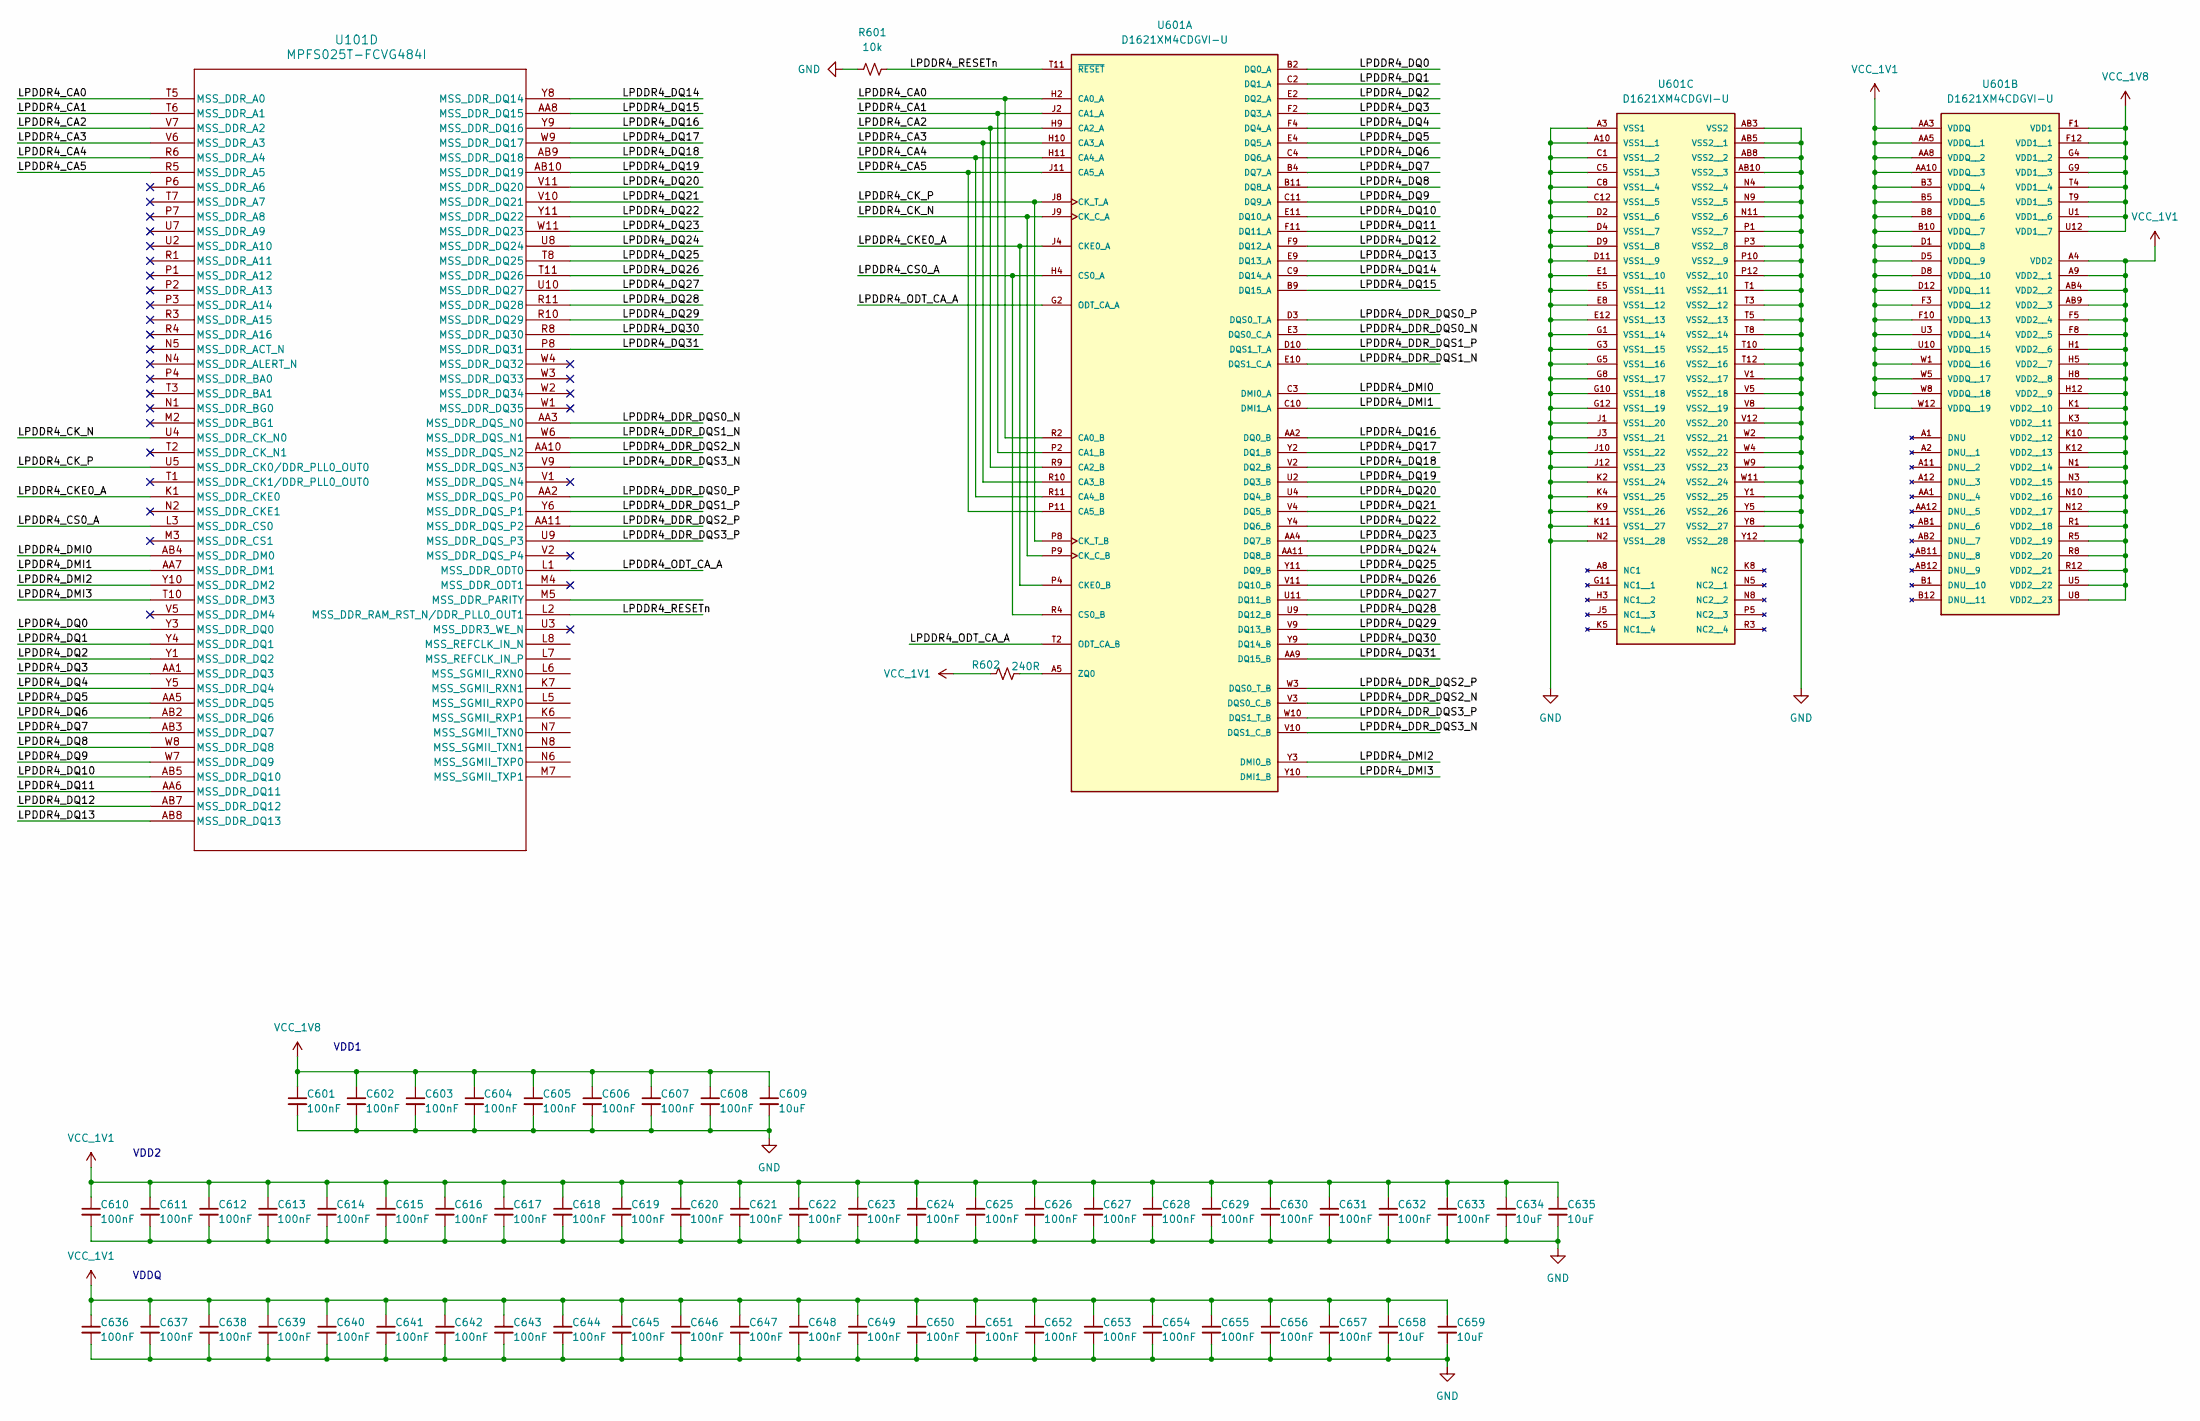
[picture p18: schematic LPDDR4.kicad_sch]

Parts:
C601, C602, C603, C604, C605, C606, C607, C608, C610, C611, C612, C613, C614, C615, C616, C617, C618, C619, C620, C621, C622, C623, C624, C625, C626, C627, C628, C629, C630, C631, C632, C633, C636, C637, C638, C639, C640, C641, C642, C643, C644, C645, C646, C647, C648, C649, C650, C651, C652, C653, C654, C655, C656, C657: 100nF; C_0201_0603Metric
C609, C634, C635, C658, C659: 10uF; C_0603_1608Metric
R601: 10k; R_0402_1005Metric
R602: 240R; R_0402_1005Metric
U101: MPFS025T-FCVG484I; MPFS250T&slash_MPFS160T&slash_MPFS095T&slash_MPFS025T-FCVG4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
U601: D1621XM4CDGVI-U; IC_D1621XM4CDGVI-U; PARTREV D00

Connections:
/LPDDR4/LPDDR4_CA0: U101.T5 (MSS_DDR_A0), U601.H2 (CA0_A), U601.R2 (CA0_B)
/LPDDR4/LPDDR4_CA1: U101.T6 (MSS_DDR_A1), U601.J2 (CA1_A), U601.P2 (CA1_B)
/LPDDR4/LPDDR4_CA2: U101.V7 (MSS_DDR_A2), U601.H9 (CA2_A), U601.R9 (CA2_B)
/LPDDR4/LPDDR4_CA3: U101.V6 (MSS_DDR_A3), U601.H10 (CA3_A), U601.R10 (CA3_B)
/LPDDR4/LPDDR4_CA4: U101.R6 (MSS_DDR_A4), U601.H11 (CA4_A), U601.R11 (CA4_B)
/LPDDR4/LPDDR4_CA5: U101.R5 (MSS_DDR_A5), U601.J11 (CA5_A), U601.P11 (CA5_B)
/LPDDR4/LPDDR4_CKE0_A: U101.K1 (MSS_DDR_CKE0), U601.J4 (CKE0_A), U601.P4 (CKE0_B)
/LPDDR4/LPDDR4_CK_N: U101.U4 (MSS_DDR_CK_N0), U601.J9 (CK_C_A), U601.P9 (CK_C_B)
/LPDDR4/LPDDR4_CK_P: U101.U5 (MSS_DDR_CK0/DDR_PLL0_OUT0), U601.J8 (CK_T_A), U601.P8 (CK_T_B)
/LPDDR4/LPDDR4_CS0_A: U101.L3 (MSS_DDR_CS0), U601.H4 (CS0_A), U601.R4 (CS0_B)
/LPDDR4/LPDDR4_DDR_DQS0_N: U101.AA3 (MSS_DDR_DQS_N0), U601.E3 (DQS0_C_A)
/LPDDR4/LPDDR4_DDR_DQS0_P: U101.AA2 (MSS_DDR_DQS_P0), U601.D3 (DQS0_T_A)
/LPDDR4/LPDDR4_DDR_DQS1_N: U101.W6 (MSS_DDR_DQS_N1), U601.E10 (DQS1_C_A)
/LPDDR4/LPDDR4_DDR_DQS1_P: U101.Y6 (MSS_DDR_DQS_P1), U601.D10 (DQS1_T_A)
/LPDDR4/LPDDR4_DDR_DQS2_N: U101.AA10 (MSS_DDR_DQS_N2), U601.V3 (DQS0_C_B)
/LPDDR4/LPDDR4_DDR_DQS2_P: U101.AA11 (MSS_DDR_DQS_P2), U601.W3 (DQS0_T_B)
/LPDDR4/LPDDR4_DDR_DQS3_N: U101.V9 (MSS_DDR_DQS_N3), U601.V10 (DQS1_C_B)
/LPDDR4/LPDDR4_DDR_DQS3_P: U101.U9 (MSS_DDR_DQS_P3), U601.W10 (DQS1_T_B)
/LPDDR4/LPDDR4_DMI0: U101.AB4 (MSS_DDR_DM0), U601.C3 (DMI0_A)
/LPDDR4/LPDDR4_DMI1: U101.AA7 (MSS_DDR_DM1), U601.C10 (DMI1_A)
/LPDDR4/LPDDR4_DMI2: U101.Y10 (MSS_DDR_DM2), U601.Y3 (DMI0_B)
/LPDDR4/LPDDR4_DMI3: U101.T10 (MSS_DDR_DM3), U601.Y10 (DMI1_B)
/LPDDR4/LPDDR4_DQ0: U101.Y3 (MSS_DDR_DQ0), U601.B2 (DQ0_A)
/LPDDR4/LPDDR4_DQ1: U101.Y4 (MSS_DDR_DQ1), U601.C2 (DQ1_A)
/LPDDR4/LPDDR4_DQ2: U101.Y1 (MSS_DDR_DQ2), U601.E2 (DQ2_A)
/LPDDR4/LPDDR4_DQ3: U101.AA1 (MSS_DDR_DQ3), U601.F2 (DQ3_A)
/LPDDR4/LPDDR4_DQ4: U101.Y5 (MSS_DDR_DQ4), U601.F4 (DQ4_A)
/LPDDR4/LPDDR4_DQ5: U101.AA5 (MSS_DDR_DQ5), U601.E4 (DQ5_A)
/LPDDR4/LPDDR4_DQ6: U101.AB2 (MSS_DDR_DQ6), U601.C4 (DQ6_A)
/LPDDR4/LPDDR4_DQ7: U101.AB3 (MSS_DDR_DQ7), U601.B4 (DQ7_A)
/LPDDR4/LPDDR4_DQ8: U101.W8 (MSS_DDR_DQ8), U601.B11 (DQ8_A)
/LPDDR4/LPDDR4_DQ9: U101.W7 (MSS_DDR_DQ9), U601.C11 (DQ9_A)
/LPDDR4/LPDDR4_DQ10: U101.AB5 (MSS_DDR_DQ10), U601.E11 (DQ10_A)
/LPDDR4/LPDDR4_DQ11: U101.AA6 (MSS_DDR_DQ11), U601.F11 (DQ11_A)
/LPDDR4/LPDDR4_DQ12: U101.AB7 (MSS_DDR_DQ12), U601.F9 (DQ12_A)
/LPDDR4/LPDDR4_DQ13: U101.AB8 (MSS_DDR_DQ13), U601.E9 (DQ13_A)
/LPDDR4/LPDDR4_DQ14: U101.Y8 (MSS_DDR_DQ14), U601.C9 (DQ14_A)
/LPDDR4/LPDDR4_DQ15: U101.AA8 (MSS_DDR_DQ15), U601.B9 (DQ15_A)
/LPDDR4/LPDDR4_DQ16: U101.Y9 (MSS_DDR_DQ16), U601.AA2 (DQ0_B)
/LPDDR4/LPDDR4_DQ17: U101.W9 (MSS_DDR_DQ17), U601.Y2 (DQ1_B)
/LPDDR4/LPDDR4_DQ18: U101.AB9 (MSS_DDR_DQ18), U601.V2 (DQ2_B)
/LPDDR4/LPDDR4_DQ19: U101.AB10 (MSS_DDR_DQ19), U601.U2 (DQ3_B)
/LPDDR4/LPDDR4_DQ20: U101.V11 (MSS_DDR_DQ20), U601.U4 (DQ4_B)
/LPDDR4/LPDDR4_DQ21: U101.V10 (MSS_DDR_DQ21), U601.V4 (DQ5_B)
/LPDDR4/LPDDR4_DQ22: U101.Y11 (MSS_DDR_DQ22), U601.Y4 (DQ6_B)
/LPDDR4/LPDDR4_DQ23: U101.W11 (MSS_DDR_DQ23), U601.AA4 (DQ7_B)
/LPDDR4/LPDDR4_DQ24: U101.U8 (MSS_DDR_DQ24), U601.AA11 (DQ8_B)
/LPDDR4/LPDDR4_DQ25: U101.T8 (MSS_DDR_DQ25), U601.Y11 (DQ9_B)
/LPDDR4/LPDDR4_DQ26: U101.T11 (MSS_DDR_DQ26), U601.V11 (DQ10_B)
/LPDDR4/LPDDR4_DQ27: U101.U10 (MSS_DDR_DQ27), U601.U11 (DQ11_B)
/LPDDR4/LPDDR4_DQ28: U101.R11 (MSS_DDR_DQ28), U601.U9 (DQ12_B)
/LPDDR4/LPDDR4_DQ29: U101.R10 (MSS_DDR_DQ29), U601.V9 (DQ13_B)
/LPDDR4/LPDDR4_DQ30: U101.R8 (MSS_DDR_DQ30), U601.Y9 (DQ14_B)
/LPDDR4/LPDDR4_DQ31: U101.P8 (MSS_DDR_DQ31), U601.AA9 (DQ15_B)
/LPDDR4/LPDDR4_ODT_CA_A: U101.L1 (MSS_DDR_ODT0), U601.G2 (ODT_CA_A), U601.T2 (ODT_CA_B)
/LPDDR4/LPDDR4_RESETn: R601.2, U101.L2 (MSS_DDR_RAM_RST_N/DDR_PLL0_OUT1), U601.T11 (~RESET)
GND: C601.2, C602.2, C603.2, C604.2, C605.2, C606.2, C607.2, C608.2, C609.2, C610.2, C611.2, C612.2, C613.2, C614.2, C615.2, C616.2, C617.2, C618.2, C619.2, C620.2, C621.2, C622.2, C623.2, C624.2, C625.2, C626.2, C627.2, C628.2, C629.2, C630.2, C631.2, C632.2, C633.2, C634.2, C635.2, C636.2, C637.2, C638.2, C639.2, C640.2, C641.2, C642.2, C643.2, C644.2, C645.2, C646.2, C647.2, C648.2, C649.2, C650.2, C651.2, C652.2, C653.2, C654.2, C655.2, C656.2, C657.2, C658.2, C659.2, R601.1, U601.A3 (VSS1), U601.A10 (VSS1__1), U601.AB3 (VSS2), U601.AB5 (VSS2__1), U601.AB8 (VSS2__2), U601.AB10 (VSS2__3), U601.C1 (VSS1__2), U601.C5 (VSS1__3), U601.C8 (VSS1__4), U601.C12 (VSS1__5), U601.D2 (VSS1__6), U601.D4 (VSS1__7), U601.D9 (VSS1__8), U601.D11 (VSS1__9), U601.E1 (VSS1__10), U601.E5 (VSS1__11), U601.E8 (VSS1__12), U601.E12 (VSS1__13), U601.G1 (VSS1__14), U601.G3 (VSS1__15), U601.G5 (VSS1__16), U601.G8 (VSS1__17), U601.G10 (VSS1__18), U601.G12 (VSS1__19), U601.J1 (VSS1__20), U601.J3 (VSS1__21), U601.J10 (VSS1__22), U601.J12 (VSS1__23), U601.K2 (VSS1__24), U601.K4 (VSS1__25), U601.K9 (VSS1__26), U601.K11 (VSS1__27), U601.N2 (VSS1__28), U601.N4 (VSS2__4), U601.N9 (VSS2__5), U601.N11 (VSS2__6), U601.P1 (VSS2__7), U601.P3 (VSS2__8), U601.P10 (VSS2__9), U601.P12 (VSS2__10), U601.T1 (VSS2__11), U601.T3 (VSS2__12), U601.T5 (VSS2__13), U601.T8 (VSS2__14), U601.T10 (VSS2__15), U601.T12 (VSS2__16), U601.V1 (VSS2__17), U601.V5 (VSS2__18), U601.V8 (VSS2__19), U601.V12 (VSS2__20), U601.W2 (VSS2__21), U601.W4 (VSS2__22), U601.W9 (VSS2__23), U601.W11 (VSS2__24), U601.Y1 (VSS2__25), U601.Y5 (VSS2__26), U601.Y8 (VSS2__27), U601.Y12 (VSS2__28); also elsewhere on the board
unnamed: R602.2, U601.A5 (ZQ0)
VCC_1V1: C610.1, C611.1, C612.1, C613.1, C614.1, C615.1, C616.1, C617.1, C618.1, C619.1, C620.1, C621.1, C622.1, C623.1, C624.1, C625.1, C626.1, C627.1, C628.1, C629.1, C630.1, C631.1, C632.1, C633.1, C634.1, C635.1, C636.1, C637.1, C638.1, C639.1, C640.1, C641.1, C642.1, C643.1, C644.1, C645.1, C646.1, C647.1, C648.1, C649.1, C650.1, C651.1, C652.1, C653.1, C654.1, C655.1, C656.1, C657.1, C658.1, C659.1, R602.1, U601.A4 (VDD2), U601.A9 (VDD2__1), U601.AA3 (VDDQ), U601.AA5 (VDDQ__1), U601.AA8 (VDDQ__2), U601.AA10 (VDDQ__3), U601.AB4 (VDD2__2), U601.AB9 (VDD2__3), U601.B3 (VDDQ__4), U601.B5 (VDDQ__5), U601.B8 (VDDQ__6), U601.B10 (VDDQ__7), U601.D1 (VDDQ__8), U601.D5 (VDDQ__9), U601.D8 (VDDQ__10), U601.D12 (VDDQ__11), U601.F3 (VDDQ__12), U601.F5 (VDD2__4), U601.F8 (VDD2__5), U601.F10 (VDDQ__13), U601.H1 (VDD2__6), U601.H5 (VDD2__7), U601.H8 (VDD2__8), U601.H12 (VDD2__9), U601.K1 (VDD2__10), U601.K3 (VDD2__11), U601.K10 (VDD2__12), U601.K12 (VDD2__13), U601.N1 (VDD2__14), U601.N3 (VDD2__15), U601.N10 (VDD2__16), U601.N12 (VDD2__17), U601.R1 (VDD2__18), U601.R5 (VDD2__19), U601.R8 (VDD2__20), U601.R12 (VDD2__21), U601.U3 (VDDQ__14), U601.U5 (VDD2__22), U601.U8 (VDD2__23), U601.U10 (VDDQ__15), U601.W1 (VDDQ__16), U601.W5 (VDDQ__17), U601.W8 (VDDQ__18), U601.W12 (VDDQ__19); also elsewhere on the board
VCC_1V8: C601.1, C602.1, C603.1, C604.1, C605.1, C606.1, C607.1, C608.1, C609.1, U601.F1 (VDD1), U601.F12 (VDD1__1), U601.G4 (VDD1__2), U601.G9 (VDD1__3), U601.T4 (VDD1__4), U601.T9 (VDD1__5), U601.U1 (VDD1__6), U601.U12 (VDD1__7); also elsewhere on the board

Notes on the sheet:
VDD2
VDD1
VDDQ

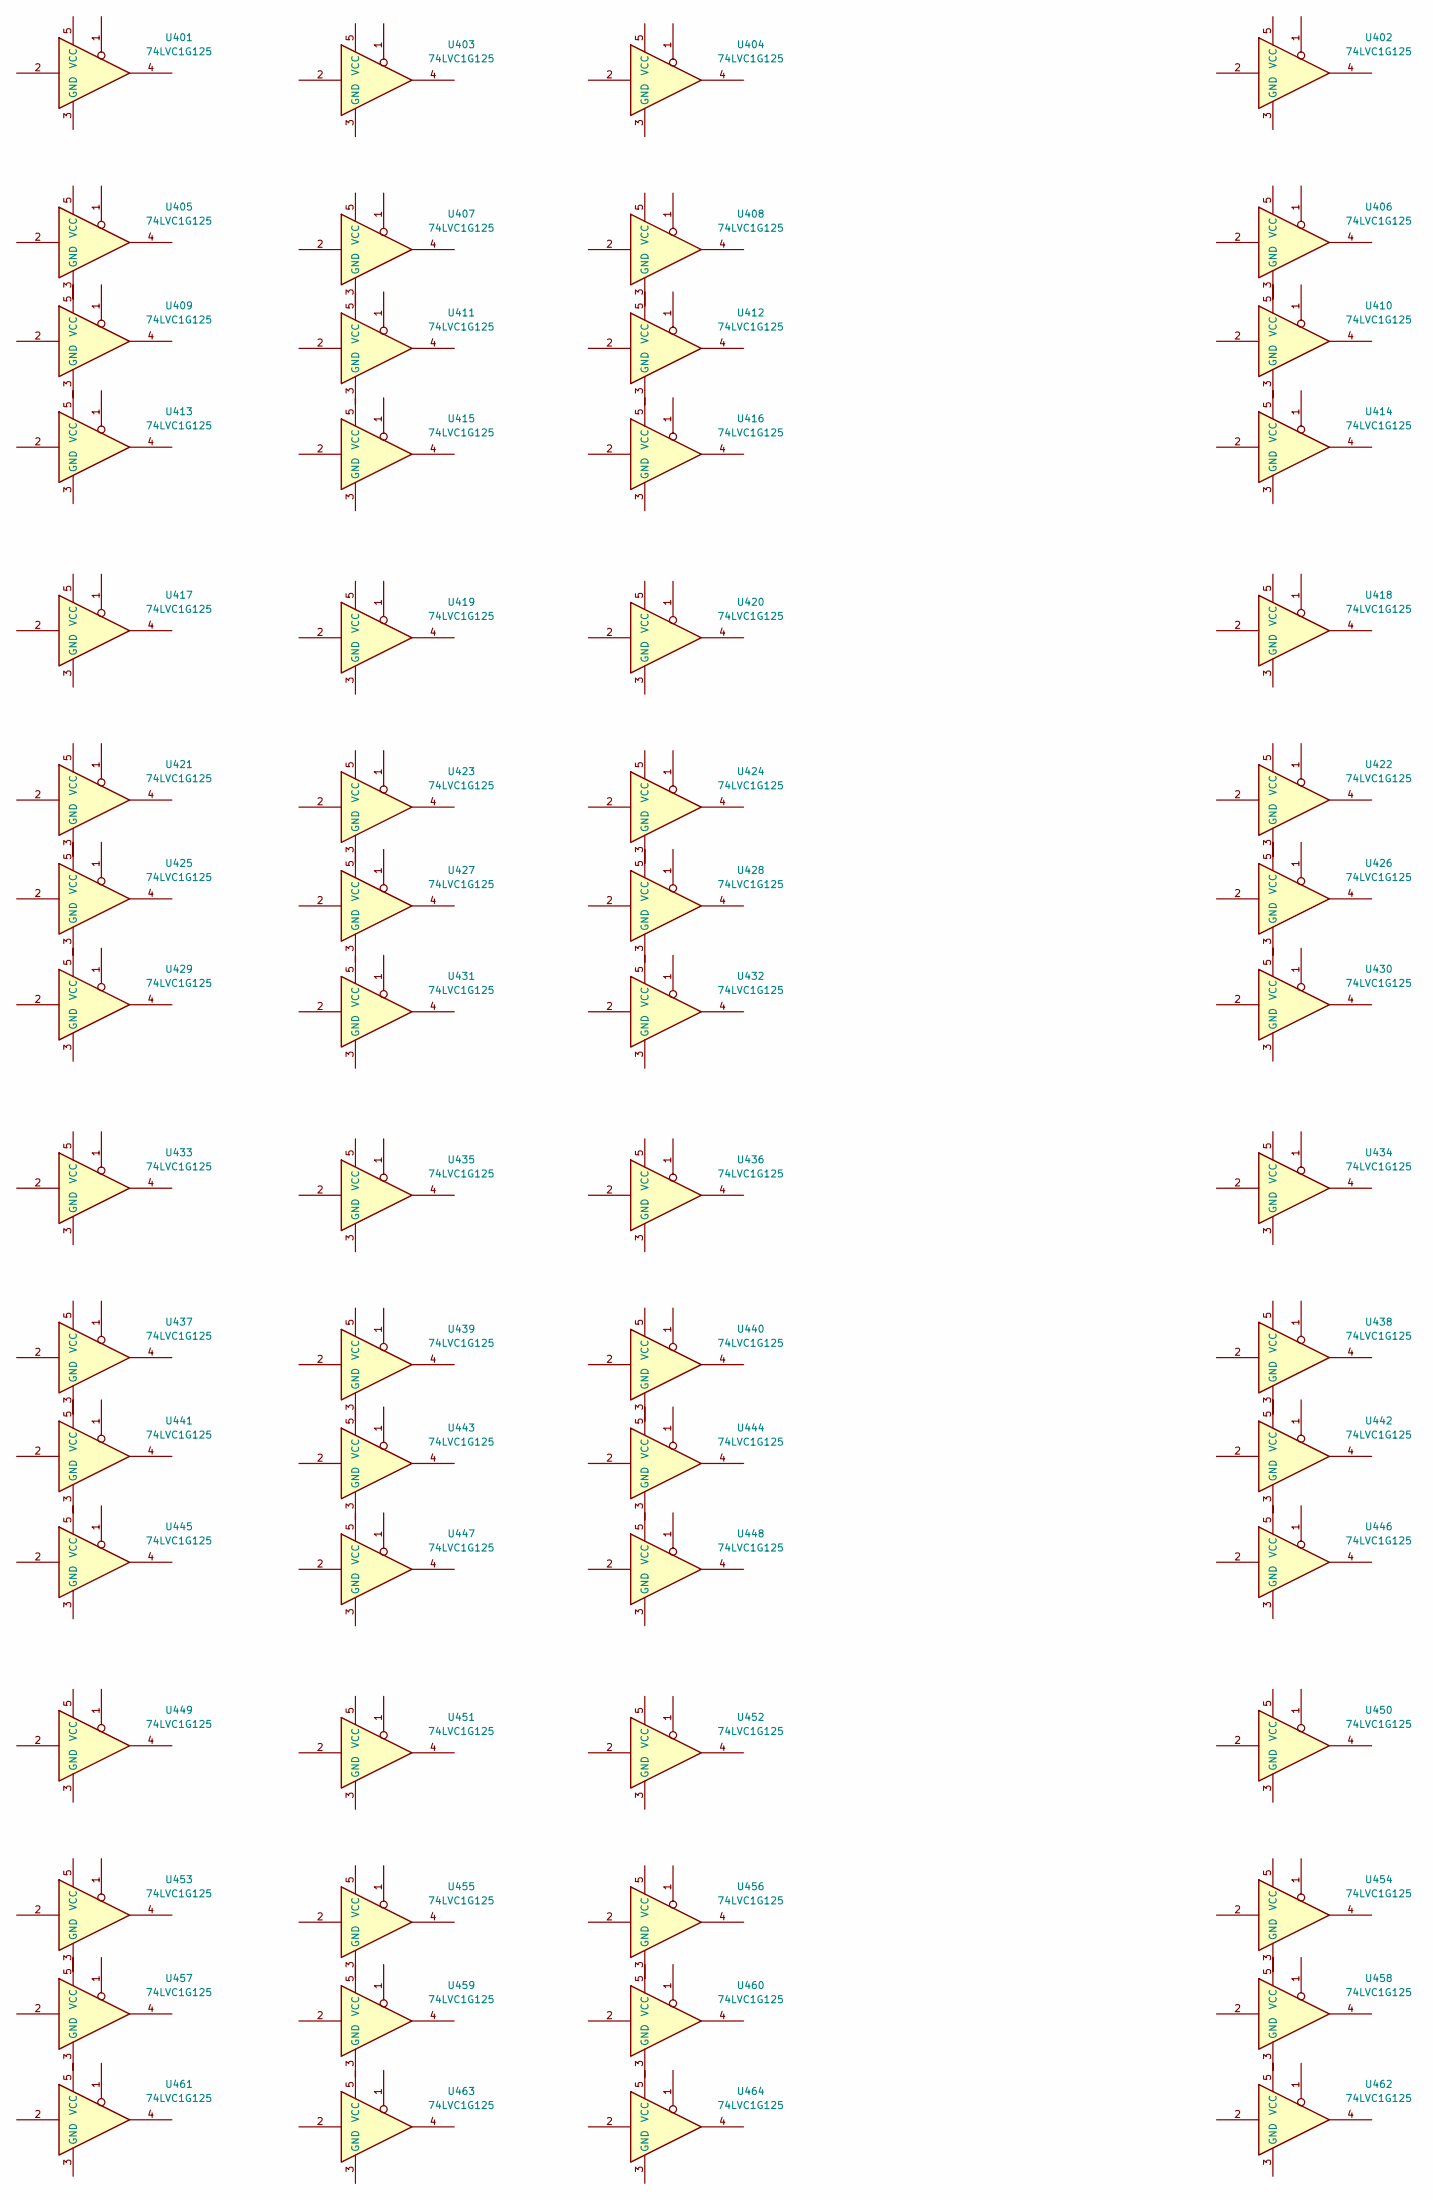
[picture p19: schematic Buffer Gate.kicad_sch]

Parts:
U401, U402, U403, U404, U405, U406, U407, U408, U409, U410, U411, U412, U413, U414, U415, U416, U417, U418, U419, U420, U421, U422, U423, U424, U425, U426, U427, U428, U429, U430, U431, U432, U433, U434, U435, U436, U437, U438, U439, U440, U441, U442, U443, U444, U445, U446, U447, U448, U449, U450, U451, U452, U453, U454, U455, U456, U457, U458, U459, U460, U461, U462, U463, U464: 74LVC1G125; DSF6_TEX

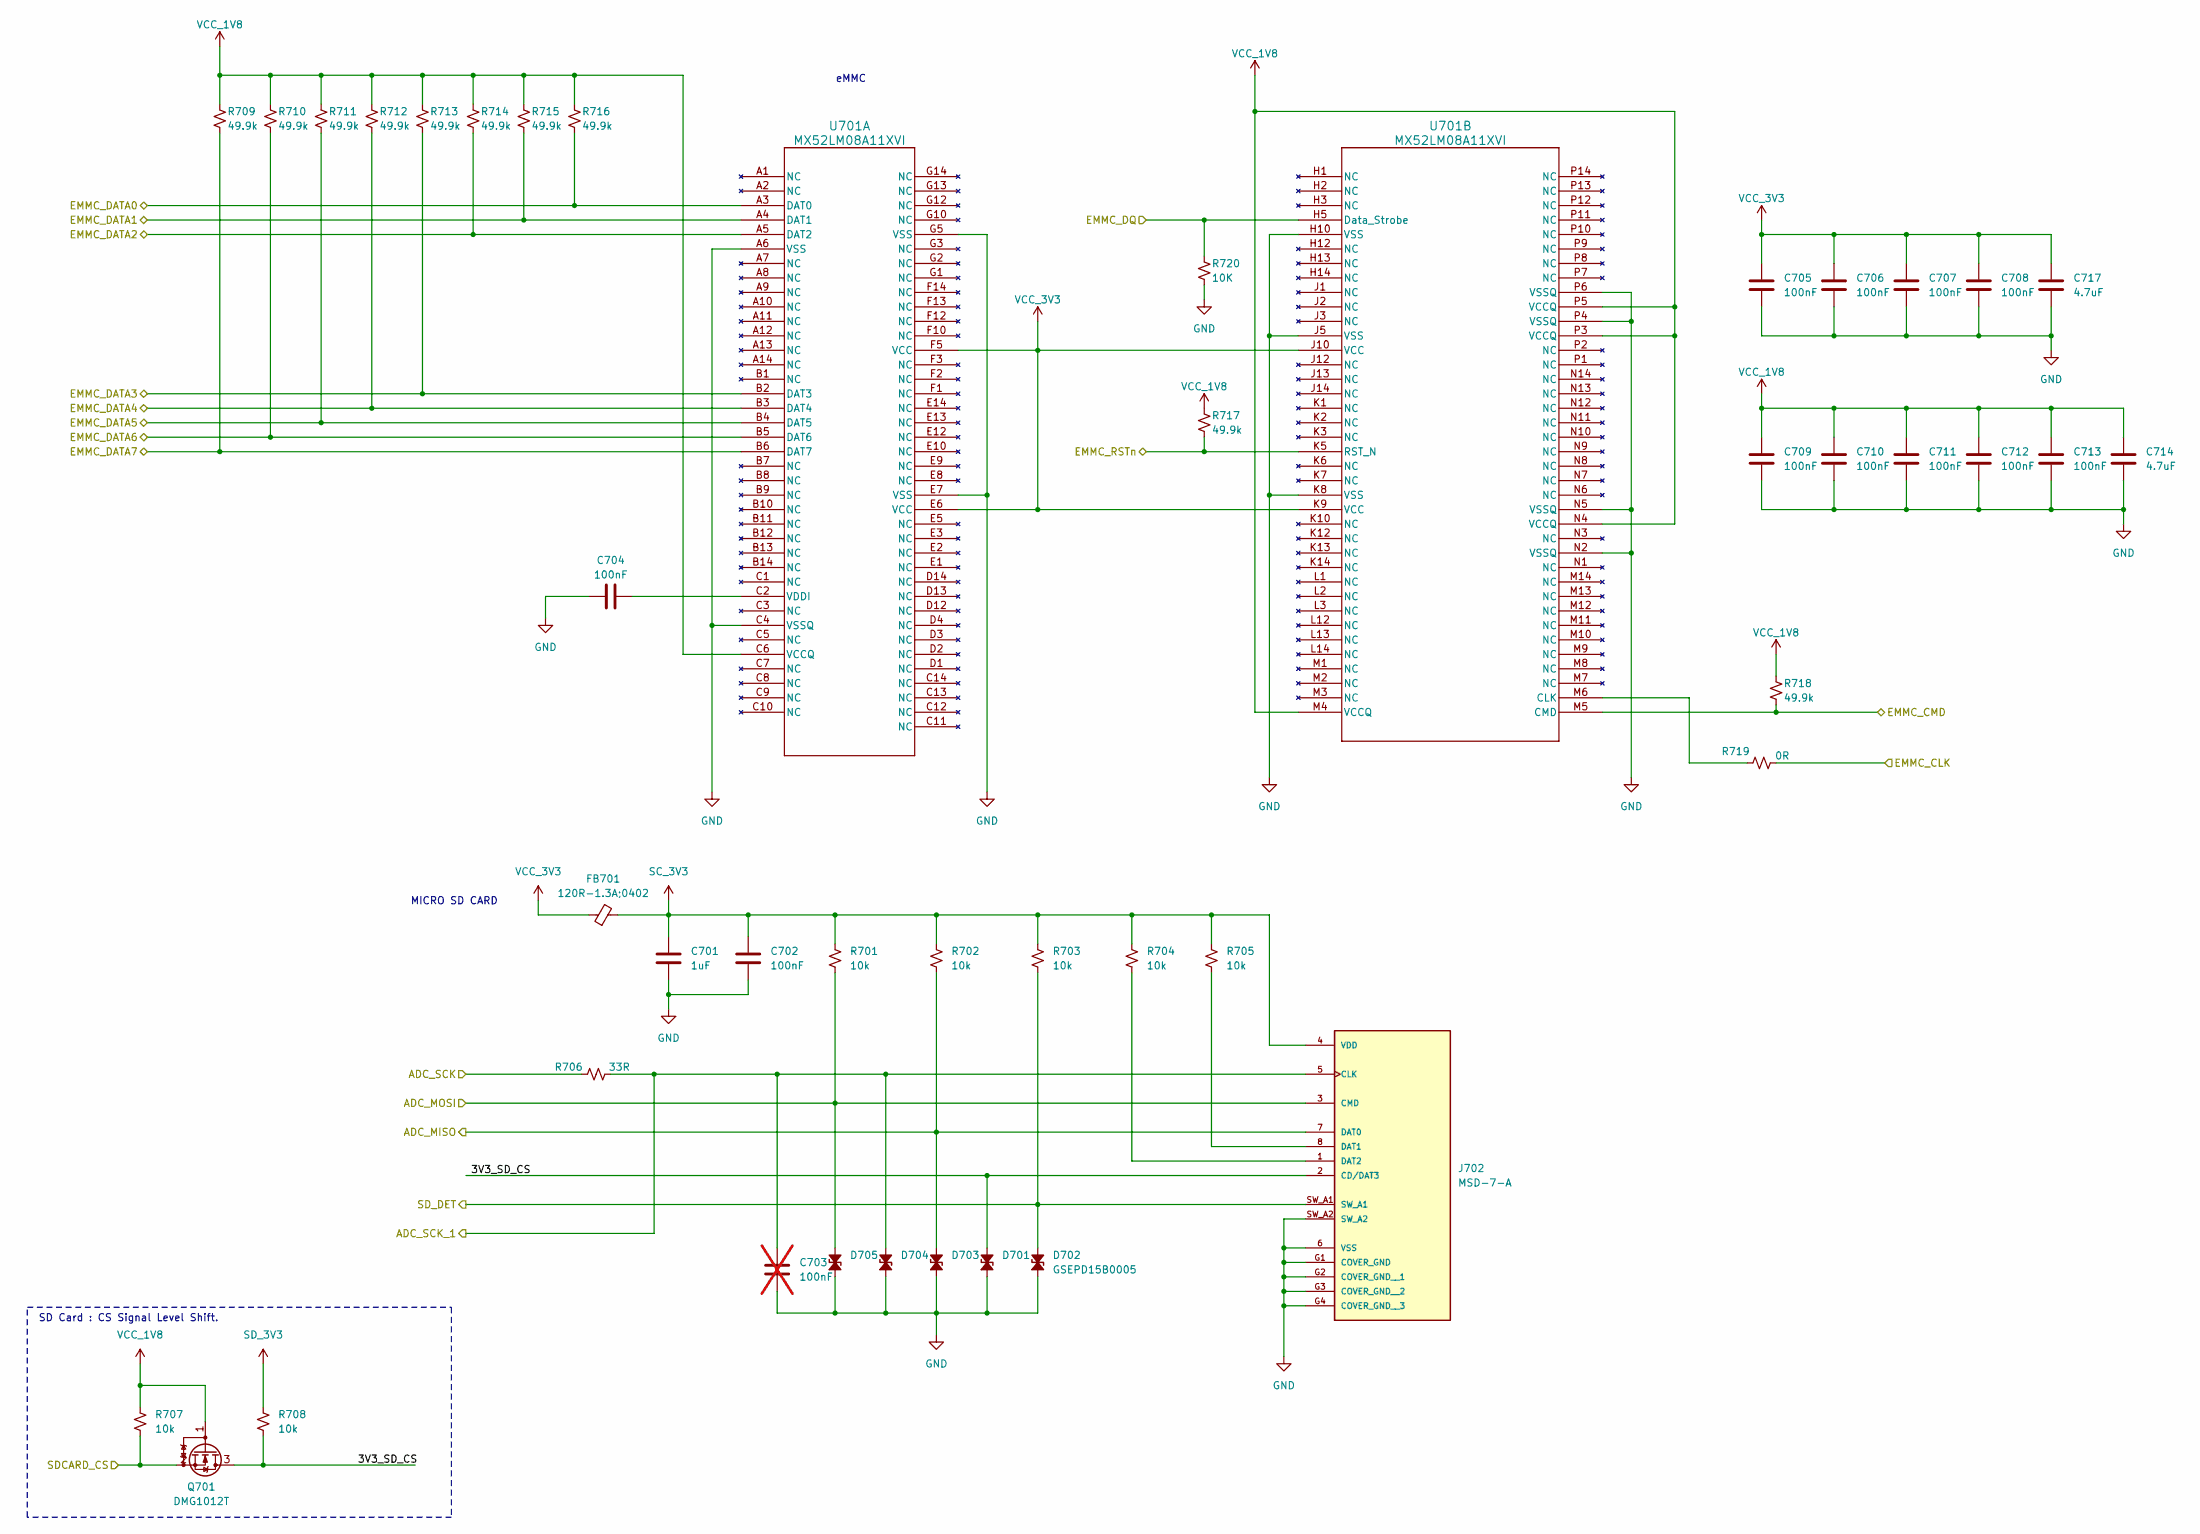
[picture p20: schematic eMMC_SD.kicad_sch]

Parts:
C701: 1uF; C_0402_1005Metric
C702, C704, C705, C706, C707, C708, C709, C710, C711, C712, C713: 100nF; C_0402_1005Metric
C703: 100nF; C_0402_1005Metric; not fitted
C714, C717: 4.7uF; C_0201_0603Metric
D701, D702, D703, D704, D705: GSEPD15B0005; D_GSEPD15B0005_01005_0402Metric
FB701: 120R-1.3A;0402; BLM15P_FBD
J702: MSD-7-A; CUI_MSD-7-A; PARTREV 1.0
Q701: DMG1012T; DMG1012-SOT-523
R701, R702, R703, R704, R705, R707, R708: 10k; R_0402_1005Metric
R706: 33R; R_0402_1005Metric
R709, R710, R711, R712, R713, R714, R715, R716, R717, R718: 49.9k; R_0402_1005Metric
R719: 0R; R_0402_1005Metric
R720: 10K; R_0402_1005Metric
U701: MX52LM08A11XVI; 153BGA_11p5x13x1_MAC

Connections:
/SD_DET: D702.2 (A2), J702.SW_A1, R703.2; also elsewhere on the board
/eMMC_SD/3V3_SD_CS: D701.2 (A2), J702.2 (CD/DAT3), Q701.3 (D), R708.2
/eMMC_SD/ADC_MISO: D703.2 (A2), J702.7 (DAT0), R702.2; also elsewhere on the board
/eMMC_SD/ADC_MOSI: D705.2 (A2), J702.3 (CMD), R701.2; also elsewhere on the board
/eMMC_SD/ADC_SCK: R706.1; also elsewhere on the board
/eMMC_SD/ADC_SCK_1: C703.1, D704.2 (A2), J702.5 (CLK), R706.2
/eMMC_SD/EMMC_CLK: R719.2; also elsewhere on the board
/eMMC_SD/EMMC_CMD: R718.2, U701.M5 (CMD); also elsewhere on the board
/eMMC_SD/EMMC_DATA0: R716.2, U701.A3 (DAT0); also elsewhere on the board
/eMMC_SD/EMMC_DATA1: R715.2, U701.A4 (DAT1); also elsewhere on the board
/eMMC_SD/EMMC_DATA2: R714.2, U701.A5 (DAT2); also elsewhere on the board
/eMMC_SD/EMMC_DATA3: R713.2, U701.B2 (DAT3); also elsewhere on the board
/eMMC_SD/EMMC_DATA4: R712.2, U701.B3 (DAT4); also elsewhere on the board
/eMMC_SD/EMMC_DATA5: R711.2, U701.B4 (DAT5); also elsewhere on the board
/eMMC_SD/EMMC_DATA6: R710.2, U701.B5 (DAT6); also elsewhere on the board
/eMMC_SD/EMMC_DATA7: R709.2, U701.B6 (DAT7); also elsewhere on the board
/eMMC_SD/EMMC_DQ: R720.1, U701.H5 (Data_Strobe); also elsewhere on the board
/eMMC_SD/EMMC_RSTn: R717.2, U701.K5 (RST_N); also elsewhere on the board
/eMMC_SD/SDCARD_CS: Q701.2 (S), R707.2; also elsewhere on the board
GND: C701.2, C702.2, C703.2, C704.1, C705.1, C706.1, C707.1, C708.1, C709.1, C710.1, C711.1, C712.1, C713.1, C714.1, C717.1, D701.1 (A1), D702.1 (A1), D703.1 (A1), D704.1 (A1), D705.1 (A1), J702.6 (VSS), J702.G1 (COVER_GND), J702.G2 (COVER_GND__1), J702.G3 (COVER_GND__2), J702.G4 (COVER_GND__3), J702.SW_A2, R720.2, U701.A6 (VSS), U701.C4 (VSSQ), U701.E7 (VSS), U701.G5 (VSS), U701.H10 (VSS), U701.J5 (VSS), U701.K8 (VSS), U701.N2 (VSSQ), U701.N5 (VSSQ), U701.P4 (VSSQ), U701.P6 (VSSQ); also elsewhere on the board
unnamed: J702.8 (DAT1), R705.2
unnamed: J702.1 (DAT2), R704.2
unnamed: C704.2, U701.C2 (VDDI)
unnamed: R719.1, U701.M6 (CLK)
SC_3V3: C701.1, C702.1, FB701.2, J702.4 (VDD), R701.1, R702.1, R703.1, R704.1, R705.1
SD_3V3: R708.1
VCC_1V8: C709.2, C710.2, C711.2, C712.2, C713.2, C714.2, Q701.1 (G), R707.1, R709.1, R710.1, R711.1, R712.1, R713.1, R714.1, R715.1, R716.1, R717.1, R718.1, U701.C6 (VCCQ), U701.M4 (VCCQ), U701.N4 (VCCQ), U701.P3 (VCCQ), U701.P5 (VCCQ); also elsewhere on the board
VCC_3V3: C705.2, C706.2, C707.2, C708.2, C717.2, FB701.1, U701.E6 (VCC), U701.F5 (VCC), U701.J10 (VCC), U701.K9 (VCC); also elsewhere on the board

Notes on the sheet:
SD Card : CS Signal Level Shift.
eMMC
MICRO SD CARD

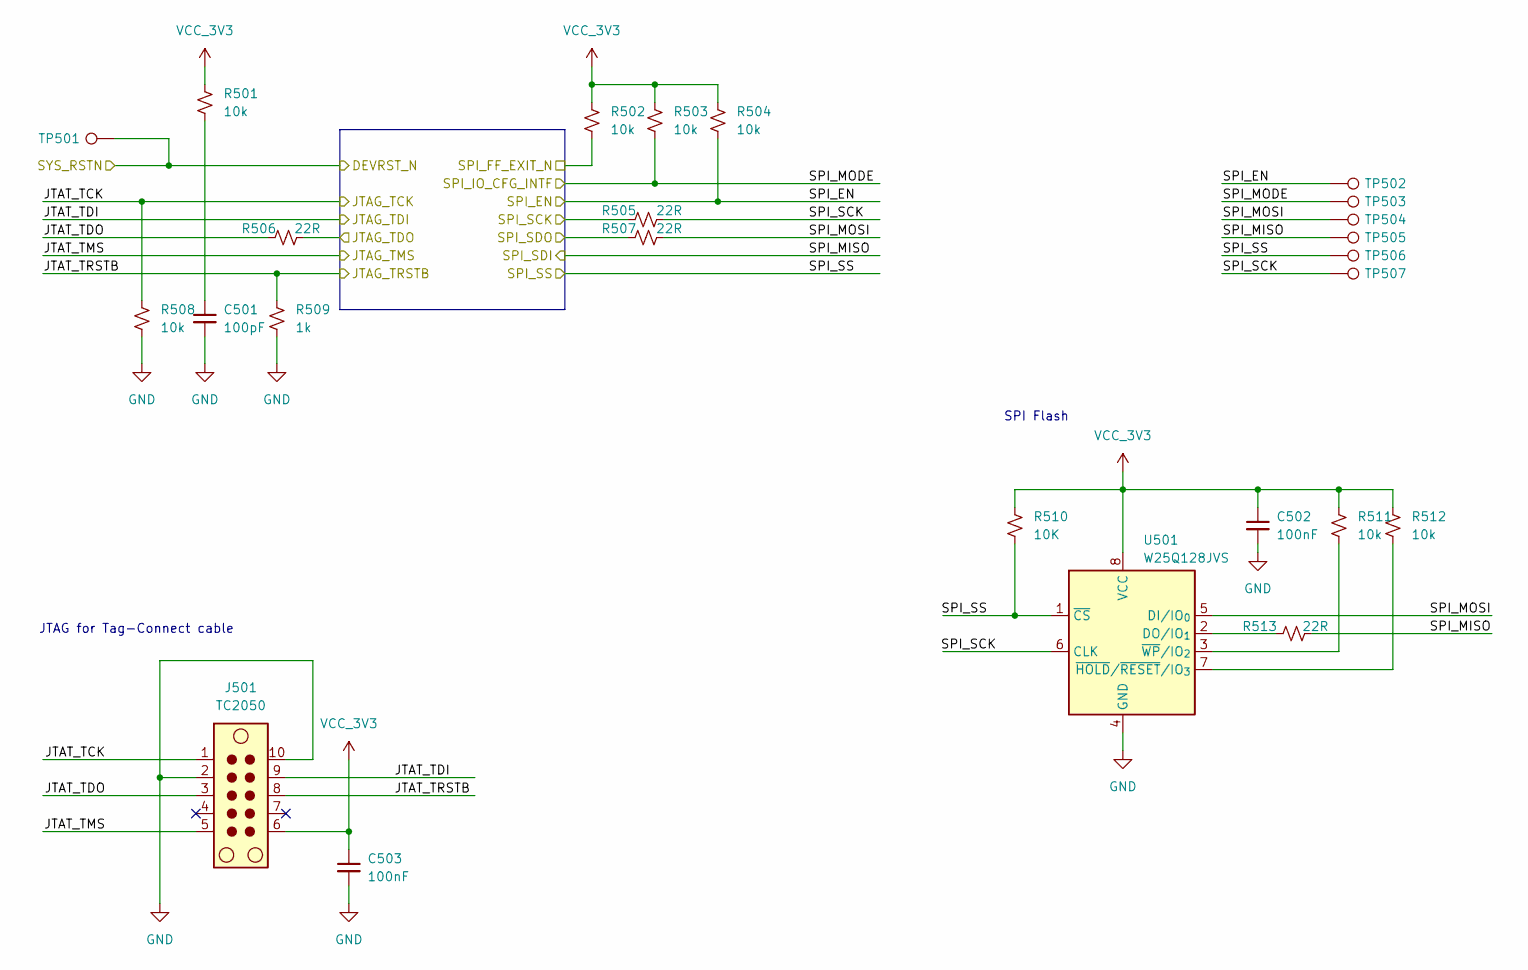
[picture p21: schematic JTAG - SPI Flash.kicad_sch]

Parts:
C501: 100pF; C_0402_1005Metric
C502, C503: 100nF; C_0402_1005Metric
J501: TC2050; Tag-Connect_TC2050-IDC-NL_2x05_P1.27mm_Vertical
R501, R502, R503, R504, R508, R511, R512: 10k; R_0402_1005Metric
R505, R506, R507, R513: 22R; R_0402_1005Metric
R509: 1k; R_0402_1005Metric
R510: 10K; R_0402_1005Metric
TP501, TP502, TP503, TP504, TP505, TP506, TP507: TestPoint; TestPoint_Pad_D1.0mm
U501: W25Q128JVS; SOIC-8_5.3x5.3mm_P1.27mm

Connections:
/JTAG - SPI Flash/DEVRST_N: TP501.1 (1_1); also elsewhere on the board
/JTAG - SPI Flash/JTAG_TDO: R506.2; also elsewhere on the board
/JTAG - SPI Flash/JTAT_TCK: J501.1, R508.1; also elsewhere on the board
/JTAG - SPI Flash/JTAT_TDI: J501.9; also elsewhere on the board
/JTAG - SPI Flash/JTAT_TDO: J501.3, R506.1
/JTAG - SPI Flash/JTAT_TMS: J501.5; also elsewhere on the board
/JTAG - SPI Flash/JTAT_TRSTB: J501.8, R509.1; also elsewhere on the board
/JTAG - SPI Flash/SPI_EN: R504.2, TP502.1 (1_1); also elsewhere on the board
/JTAG - SPI Flash/SPI_FF_EXIT_N: R502.2; also elsewhere on the board
/JTAG - SPI Flash/SPI_MISO: R513.2, TP505.1 (1_1); also elsewhere on the board
/JTAG - SPI Flash/SPI_MODE: R503.2, TP503.1 (1_1); also elsewhere on the board
/JTAG - SPI Flash/SPI_MOSI: R507.2, TP504.1 (1_1), U501.5 (DI/IO_{0})
/JTAG - SPI Flash/SPI_SCK: R505.1, R505.2, TP507.1 (1_1), U501.6 (CLK); also elsewhere on the board
/JTAG - SPI Flash/SPI_SDO: R507.1; also elsewhere on the board
/JTAG - SPI Flash/SPI_SS: R510.2, TP506.1 (1_1), U501.1 (~CS); also elsewhere on the board
GND: C501.2, C502.2, C503.2, J501.2, J501.10, R508.2, R509.2, U501.4 (GND); also elsewhere on the board
unnamed: C501.1, R501.2
unnamed: R513.1, U501.2 (DO/IO_{1})
unnamed: R512.2, U501.7 (~HOLD/~RESET/IO_{3})
unnamed: R511.2, U501.3 (~WP/IO_{2})
VCC_3V3: C502.1, C503.1, J501.6, R501.1, R502.1, R503.1, R504.1, R510.1, R511.1, R512.1, U501.8 (VCC); also elsewhere on the board

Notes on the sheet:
SPI Flash
JTAG for Tag-Connect cable

Board: 4 copper layers, 251 parts (0 on the bottom side), 150 nets, no tracks yet.

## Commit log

2026-06-16 Initial commit of Cryon-ICE project and component library
    [10155435-00011LF.STEP, 10155435-00011LF.stp, 12-88481.step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]
2026-06-16 Batch converted all 3D model absolute paths to relative
    [Cryon-ICE.kicad_pcb]
2026-06-16 Updated netlist connection rules
    [Cryon-ICE.kicad_pcb]
2026-06-17 Added micro-sd to schematic
    [BLM15P_FBD.iges, Cryon-ICE.kicad_pcb, Cryon-ICE.kicad_sch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]
2026-06-17 Added eMMC
    [153BGA_11p5x13x1_MAC.iges, Cryon-ICE.kicad_pcb, Cryon-ICE.kicad_sch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]
